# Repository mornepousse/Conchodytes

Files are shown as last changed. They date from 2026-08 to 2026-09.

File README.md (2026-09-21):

<h1 align="center">Conchodytes</h1>

<p align="center">
  <em>The shrimp that lives inside another's shell.</em><br>
  <em>La crevette qui vit dans la coquille d'un autre.</em>
</p>

---

## Firmware

The mouse runs the [KeSp firmware](https://github.com/mornepousse/KeSp_firmware)
(role `MOUSE`: PMW3389, three clicks, wheel, HID relayed to the dongle's slot 2).
Since 2026-09-21 **its board lives here**, not in the firmware repository:

- `boards/conchodytes/` — `board.h` (pinout, netlist-checked), `sdkconfig.defaults`,
  `test_pins.c` (the pinout contract);
- `firmware/` — the KeSp firmware as a git submodule, pinned on a release
  (`git submodule update --init`);
- `.github/workflows/firmware.yml` — calls the firmware's reusable workflow:
  every push builds `conchodytes_<version>.bin` (+ `_full.bin`), a `v*` tag
  publishes a release here.

```bash
scripts/test-pins.sh                                    # pinout contract, host, no toolchain
cd firmware && export IDF_COMPONENT_CHECK_NEW_VERSION=0 && \
idf.py -B build_conchodytes -DBOARD_DIR=../boards/conchodytes -DSDKCONFIG=build_conchodytes/sdkconfig build
esptool --chip esp32s3 -p /dev/ttyACM0 write_flash 0x20000 build_conchodytes/KeSp.bin
```

To take a newer firmware: `cd firmware && git fetch --tags && git checkout vX.Y.Z`,
then commit the submodule bump; read the firmware's release notes first (a
board macro may have been added — the pin contract will say).

## Firmware

The mouse runs the [KeSp firmware](https://github.com/mornepousse/KeSp_firmware)
(role `MOUSE`). Its board definition, pinout contract and firmware releases live
in **[Conchodytes-firmware](https://github.com/mornepousse/Conchodytes-firmware)**;
this repository is the hardware (PCB, notes, bring-up).

## English

A **sleeper mouse**: a replacement PCB for a Logitech M100 shell, keeping the
outer appearance of a cheap office mouse while carrying a **PMW3389** sensor and
a **wireless link to the [KeSp dongle](https://github.com/mornepousse/KeSp_dongle)** — the same receiver as the
[Niphargus](https://github.com/mornepousse/Niphargus) keyboard.

The shell is a fixed constraint: click switches, optical wheel encoder and sensor
positions are imposed by the M100 case and are locked in the layout.

Electronics reuse the reviewed and routed blocks of Niphargus — ESP32-S3 +
nRF24L01+, TP4056 charging with DW01A/FS8205 protection, HT7833 LDO, USB-C with
ESD protection.

## Français

Une **souris sleeper** : un PCB de remplacement pour coque Logitech M100, qui
garde l'apparence d'une souris de bureau bon marché tout en embarquant un capteur
**PMW3389** et une **liaison sans fil vers le [dongle KeSp](https://github.com/mornepousse/KeSp_dongle)** — le même récepteur
que le clavier [Niphargus](https://github.com/mornepousse/Niphargus).

La coque est une contrainte figée : les positions des clics, de l'encodeur
optique de molette et du capteur sont imposées par le boîtier M100, et
verrouillées dans le layout.

L'électronique reprend les blocs relus et routés du Niphargus — ESP32-S3 +
nRF24L01+, charge TP4056 avec protection DW01A/FS8205, LDO HT7833, USB-C protégé.

**État (2026-08-25)** — capteur **validé au banc** : identifié, SROM téléversé,
déplacement lu, sur trois reworks (voir `NOTES-V2.md`). Le firmware de banc est
dans `bringup/`.

**État (2026-08-07)** — schéma complet et vérifié par netlist, board **routé,
0 pad non connecté**. Le contour et les positions imposées par la coque viennent
du fork `USB-Mouse` ; l'alimentation, la charge, l'USB et la radio sont repris
du Niphargus. Reste à nettoyer le DRC (18 `copper_edge_clearance`) et à mesurer
la coque pour figer le contour définitif.

---

## Repository layout · Organisation

| Path | Contents |
|---|---|
| `hardware/pcb/` | KiCad project — `conchodytes.kicad_pro` |
| `scripts/` | Anti-regression checks (same pipeline as Niphargus) |
| `docs/` | Design notes |

### Fabrication

The two projects stay **independent**. They are only merged **at gerber export
time**, so the mouse board is panelised into the free space of the Niphargus
panel and costs almost nothing to make.

Les deux projets restent **indépendants**. Ils ne sont réunis qu'**au moment de
l'export gerber**, la carte souris venant se loger dans le vide du panneau
Niphargus — le PCB revient alors à presque rien.

### Anti-regression · Anti-régression

```sh
./scripts/check.sh --fast   # ERC vs committed baseline
./scripts/check.sh          # + full DRC
```

### Bloc capteur

| | |
|---|---|
| **PMW3389** | SPI partagé avec le nRF24 (`SCK_L`/`MOSI_L`/`MISO_L`), plus `SNS_NCS` et `SNS_MOTION`. Mode SPI **3**, `fSCLK` ≤ 2 MHz |
| **Alimentation** | ⚠️ VDD et VDDPIX **ne sont pas en 3,3 V** — rail dédié **2,0 V** par LDO (1,80-2,10 V, maximum **absolu** 2,10). VDDIO reste en 3,3 V |
| **Optique** | lentille **LM19-LSI**, commune au PMW3360 et au PMW3389 — celle d'origine de la M100 est faite pour le PAW3526 et ne convient pas |
| **Molette** | encodeur **optique** : LD1 éclaire une roue à 60 fentes, LQ1 la lit. ⚠️ `LQ1` (marquage `H6Y07`) est un capteur **VCC / GND / DATA**, PAS un double phototransistor — la v1 le câblait à l'envers, voir `NOTES-V2.md` §1bis |
| **Clics** | SPDT, COM à la masse, **NO et NC** tirés chacun au 3,3 V — lire les deux contacts en parallèle supprime le rebond |

Affectation des GPIO du S3, en évitant les broches de strapping :

| Signal | GPIO | Broche du module | | Signal | GPIO | Broche |
|---|---|---|---|---|---|---|
| `SNS_NCS` | 17 | 10 | | `SW_LEFT` | 10 | 18 |
| `SNS_MOTION` | 18 | 11 | | `SW_RIGHT` | 11 | 19 |
| `ENC_A` (DATA) | 7 | 7 | | `SW_MID` | 12 | 20 |
| `ENC_LED` ¹ | 9 | 17 | | `SW_LEFT_NC` | 5 | 5 |
| | | | | `SW_RIGHT_NC` | 4 | 4 |
| | | | | `SW_MID_NC` | 6 | 6 |

¹ `GPIO9` portait `ENC_B` en v1, sur un montage faux. En v2 il **commande la
cathode de LD1** — la LED de molette peut donc être éteinte par le firmware,
ce qui compte sur une souris à batterie. `ENC_A` (GPIO7) est le seul signal de
l'encodeur, et c'est `ADC1_CH6`.

⚠️ Ne pas confondre **GPIO** et **numéro de broche du module** : ce tableau
donnait auparavant les broches en les présentant comme des GPIO.

⚠️ **`SW_LEFT_NC` et `SW_RIGHT_NC` étaient inversés ici** jusqu'au 2026-08-25.
Le tableau annonçait GPIO4 à gauche et GPIO5 à droite ; la netlist dit l'inverse
— GPIO4 va à `SW2.3` (clic droit, R109) et GPIO5 à `SW1.3` (clic gauche, R108).
Comme l'anti-rebond apparie NO et NC du **même** bouton, écrire le firmware sur
l'ancien tableau croisait les deux clics.

Le reste du brochage, relevé à la netlist au `kicad-cli` le 2026-08-25 :

| Signal | Broche | GPIO | | Signal | Broche | GPIO |
|---|---|---|---|---|---|---|
| `SCK_L` | 31 | 38 | | `CSN_1` (nRF) | 38 | 2 |
| `MISO_L` | 32 | 39 | | `CE_1` (nRF) | 39 | 1 |
| `MOSI_L` | 33 | 40 | | `IRQ_1` (nRF) | 34 | 41 |
| `VBAT_SENSE` ² | 21 | 13 (ADC2_CH2) | | `D-` / `D+` | 13 / 14 | 19 / 20 |
| J1 `TX` / `RX` | 37 / 36 | 43 / 44 | | J1 `IO0` | 27 | 0 |

² En **v2**, `VBAT_SENSE` passe sur la broche 12 = **GPIO8 = ADC1_CH7**. L'ADC2
de l'ESP32-S3 est partagé avec le driver Wi-Fi ; tant que la mesure y reste, le
Wi-Fi est interdit sur cette carte. Voir `NOTES-V2.md` point 7.

Les lignes SPI et de contrôle portent chacune 100 Ω en série (R16/R18/R30,
R36/R39/R41) — sans effet à 2 MHz.

Les contacts NC des trois clics sont câblés sur GPIO4/5/6, chacun avec son
pull-up 10 k (R108-R110). Au repos NC est fermé sur COM donc bas, NO ouvert donc
haut ; au clic ils s'inversent. **Pendant le rebond les deux sont hauts** — le
firmware garde alors l'état précédent, ce qui élimine le double-clic sans aucun
filtrage temporel.

Les six empreintes imposées par la coque — SW1/SW2/SW3, LD1, LQ1, U2 — sont
**verrouillées** dans le layout et liées à leurs symboles. Ne pas les renommer :
le F8 les dissocierait et leurs positions seraient perdues.

## Historique · History

| Étape | Ce qui s'est passé |
|---|---|
| **REV1** | Premier tirage. Trois défauts de conception trouvés au banc, tous documentés dans `NOTES-V2.md` : `LQ1` câblé à l'envers (§1bis), `U100` — le LDO du capteur — pattes 2 et 3 croisées, et `U2` monté à 180°. |
| **2026-08-25** | Bring-up du capteur. La puce n'est **pas** un PMW3360 mais un **PMW3389** (`Product_ID = 0x47`) : identité lue, SROM téléversé, déplacement mesuré. Rail capteur corrigé au fer, **2,01 V mesuré**. Rotation de 180° confirmée par la mesure — les deux axes inversés, biais 100 % sur 76 échantillons. |
| **REV2.0.0** | Schéma corrigé et gerbers partis en fabrication : `LQ1` recâblé sur `+3V3`, `D100` supprimée, `VBAT_SENSE` déplacé sur ADC1, `U100` corrigé, `LD1` passée en cathode pilotée. |
| **2026-08-26** | Firmware complet et lien radio. La souris parle au dongle KaSe sur le slot RF 2 — le code vit comme septième variante de carte dans `KeSp_firmware`, pas dans un dépôt séparé. |

### Ce que la mise au point du 26 août a trouvé

Quatre défauts, chacun établi par une mesure prise **aux deux extrémités du
lien** — compteurs de la souris d'un côté, `RF_STATUS` du dongle de l'autre.

| Défaut | Avant | Après |
|---|---|---|
| Bascule de mode SPI sous un CS déjà abaissé — bus partagé entre le capteur (mode 3) et la radio (mode 0) | 1 trame acquittée sur 738 | 693 sur 693 |
| Scrutation du dongle à 10 ms, pour une FIFO nRF24 de 3 paquets | 3135 acceptées sur 8356 (37,5 %) | 99-100 % |
| Déplacement des trames non acquittées **jeté** au lieu d'être réaccumulé | la moitié du geste disparaissait | distance conservée |
| Résolution jamais écrite : la puce restait à son défaut | 5000 cpi | 1000 cpi, comme la M100 |

### Ce qui reste ouvert

Un tremblement d'**origine optique** que le firmware ne peut pas corriger :
`SQUAL` mesuré entre 30 et 55 là où ~80 est attendu, et le capteur produit sur
certaines surfaces des dérives cohérentes de ~1000 comptes en trois secondes,
souris immobile — indiscernables d'un geste lent volontaire.

Deux pistes, par ordre de coût croissant, détaillées au **§8 de `NOTES-V2.md`** :

1. **`R102`** vaut 330 Ω sous 3,3 V, soit ~6,8 mA dans `LD1`, quand la M100
   d'origine en fait passer 2,6 mA. La LED de molette tourne à près du triple de
   son intensité prévue, en permanence, contre le capteur. **820 Ω** reproduit
   le point de fonctionnement d'origine. Un composant.
2. **Le montage à 180° de `U2`** échange peut-être les chemins d'illumination et
   d'imagerie de la lentille, ce qui expliquerait l'image à la fois sombre en
   moyenne et saturée par endroits. Si c'est le cas, la rotation d'empreinte
   prévue en REV2 corrige le tremblement **et** le sens des axes d'un coup.

## Credits

Outline and mechanical positions derive from
[RandomDelta6/USB-Mouse](https://github.com/RandomDelta6/USB-Mouse), a working
USB mouse PCB reusing the original optical assembly.

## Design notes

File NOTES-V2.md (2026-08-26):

# Conchodytes v2 — relevés de banc

Notes prises au montage et au test de la **v1**, à reporter dans le layout de la
v2. Chaque point vient d'une observation sur carte réelle, pas d'une relecture
de schéma.

**Banc au 2026-08-25** — chaîne d'alimentation validée : batterie → protection
DW01A/FS8205 → Q2 (power-path) / D52 → **U20 HT7833 : 3,3 V mesuré et bon en
sortie**.

**Capteur validé le 2026-08-25**, après deux reworks au fer — le rail (`U100`
pins 2 et 3 croisées, voir `NOTE-LDO-PMW3360.md`) et la LED (§6) : identité lue,
SROM téléversé, déplacement mesuré, rail **mesuré à 2,01 V**. Le firmware de banc qui a servi
est dans `bringup/` — carte sur `/dev/ttyUSB2` via le FT2232 sur J1.

---

## 0. La puce n'est pas un PMW3360 — c'est un PMW3389

Lu sur la carte le 2026-08-25 : `Product_ID = 0x47`, `Inverse_Product_ID = 0xB8`,
`Revision_ID = 0x01`. Ce sont les valeurs par défaut du **PMW3389DM-T3QU**
(datasheet PixArt, Version 1.0 | 07 sep 2017, Table du §5.1, p. 20), pas celles
du PMW3360 (0x42 / 0xBD, p. 18 de sa propre datasheet). C'est **voulu** ; c'est
le dépôt qui n'avait pas suivi.

*(Coquille de la datasheet 3389 au passage : elle annonce `Inverse_Product_ID`
= 0xB9, alors que `0x47 ^ 0xFF = 0xB8`, et c'est bien 0xB8 que la carte renvoie.
Attendre le complément exact — c'est en prime une vérification de bus gratuite.)*

### Ce que les deux puces ne partagent pas

| | PMW3360 | PMW3389 |
|---|---|---|
| `Product_ID` | 0x42 | **0x47** |
| Résolution | `Config1` (0x0F), 8 bits | **`Resolution_L`/`_H` (0x0E/0x0F), 16 bits** |
| 0x0D | `Control` | **`Ripple Control`** |
| Config5 | 0x2F | **0x2E/0x2F** |
| LiftCutoff timeout | 0x58 / 0x5A | **0x71 / 0x72** |
| PWM | — | **0x73 / 0x74** |
| `tSRAD` (lecture normale) | 35 µs | **160 µs** |
| `tSWW` / `tSWR` | 120 µs | **180 µs** |
| Résistance de LED (référence) | 39 Ω sur 1,9 V | **13 Ω sur 1,9 V** |
| **Blob SROM** | — | **différent, 99,6 % des octets** |

Ce qui **ne** change **pas** : `VDD` 1,80/1,90/**2,10** V, `VDDIO` 1,80-3,60 V,
`fSCLK` ≤ 2 MHz, la lentille **LM19-LSI**, le brochage 16 broches, et la broche
15 `LED_P` en anode de la LED interne.

⚠️ Sur le 3389 les **2,10 V sont un maximum absolu** (Table 3, p. 15), pas
seulement le haut de la plage d'emploi comme sur le 3360.

### À reprendre dans le dépôt

- le symbole KiCad `U2` porte encore la valeur `PMW3360` ;
- `PMW3360.lib`, `PMW3360.pretty`, `NOTE-LDO-PMW3360.md` gardent leurs noms —
  le brochage 16 broches étant identique, l'empreinte reste valide, seul le nom
  ment ;
- le BOM et la commande LCSC.

---

## 1. U2 (PMW3389) — rotation de 180°

Le capteur est du bon côté de la carte, mais **orienté à l'envers** : l'axe Y est
inversé par rapport à l'axe de la souris.

| | v1 | v2 |
|---|---|---|
| Face | F.Cu | F.Cu (inchangé) |
| Position | (96,53 / 116,38) | inchangée |
| Rotation | 0° | **180°** |

La position ne bouge pas — elle est imposée par la coque M100 et l'empreinte est
verrouillée dans le layout. Seule la rotation change.

⚠️ **Ne pas renommer U2** en faisant la modification : le README rappelle que les
six empreintes imposées par la coque (SW1/SW2/SW3, LD1, LQ1, U2) sont liées à
leurs symboles, et qu'un F8 les dissocierait — leurs positions seraient perdues.

### ✅ Sens de rotation confirmé par la mesure (2026-08-25)

Protocole : passes dans **une seule direction**, souris soulevée pour le retour,
de sorte que le signe ne s'annule pas. Lecture par `Motion_Burst`, sommes signées
sur les échantillons amples.

| Geste | Convention HID | Mesuré | Biais |
|---|---|---|---|
| vers la **droite** | X positif | **X négatif** | 100,0 % sur 76 échantillons |
| vers l'**avant** | Y négatif (curseur monte) | **Y positif** | 99,8 % sur 71 échantillons |

**Les DEUX axes sont inversés.** C'est la signature exacte d'une rotation de
180° : une rotation quelconque mélangerait les axes (les deux paires varieraient
ensemble), un miroir n'en inverserait qu'un. Ici chaque axe reste propre — le
biais hors axe est de 50 % et d'amplitude 12 fois moindre — et les deux sont
retournés.

La correction proposée ci-dessus est donc la bonne, et le repli aussi :

- **rotation de 180° dans le layout** → les deux axes se remettent d'aplomb sans
  une ligne de firmware ;
- **si la lentille ne peut pas suivre** → le firmware nie `dx` et `dy`, deux
  signes moins, et le placement ne bouge pas.

Il ne reste donc plus qu'à vérifier **mécaniquement** si la LM19-LSI accepte la
rotation. La question logicielle, elle, est réglée.

**Question ouverte — la lentille.** Le PMW3389 travaille avec la lentille
**LM19-LSI** — la même que le 3360 (Figure 7, p. 10, et la note d'application
citée p. 13). Elle a ses propres ergots d'alignement sur le capteur et sur la
coque. Tourner le capteur de 180° peut imposer de tourner la lentille d'autant,
ce que la coque n'autorise peut-être pas. À trancher **avant** de figer le
layout : si la lentille ne peut pas suivre, la correction d'axe doit se faire
côté firmware plutôt que dans le placement.

*(Les deux datasheets sont maintenant indexées dans lemia : PMW3360DM-T2QU
`doc_id 6838`, PMW3389DM-T3QU `doc_id 6839`.)*

**Indice de banc à recouper avec ce point.** Le 2026-08-25, capteur à plat sur
l'établi **sans coque**, `SQUAL` fluctuait fortement au repos — de 12 à 73 sans
que rien ne bouge. Sur une optique correctement posée il devrait être stable. La
Table 4 (p. 15) veut **2,2 à 2,6 mm** entre le plan de référence de la lentille
et la surface suivie ; nue sur un établi la carte n'y est pas. À revérifier une
fois dans la M100 : si ça fluctue encore, c'est la lentille ou sa hauteur, pas le
capteur.

## 1bis. ⚠️ LQ1 EST CÂBLÉ À L'ENVERS — défaut de conception (BLOQUANT v2)

**Établi le 2026-08-26**, en confrontant le schéma d'origine de la M100
(`USB-Mouse-main/Mouse.sch`) au câblage de la Conchodytes.

`LQ1` n'est **pas** un double phototransistor A/COM/B. C'est un capteur à trois
fils **VCC / GND / DATA**. Marquage relevé sur le composant : **`H6Y07`**
(aucune datasheet trouvée).

### Le schéma d'origine, sans ambiguïté

```
(900, 6350) → label "Pin_4"    = LQ1 broche 1
(900, 6450) → label "Pin_2J"   = LQ1 broche 2
(900, 6550) → power:GNDREF     = LQ1 broche 3
```

`Pin_2J` n'est pas une masse : c'est le nœud d'alimentation, alimenté depuis
`Pin_2` à travers R12, et **partagé avec l'anode de LD1**.

### La comparaison

| `LQ1` | M100 d'origine | Conchodytes v1 | |
|---|---|---|---|
| broche 1 | `Pin_4` — **sortie DATA** | `ENC_A` + tirage 10 k | ✅ |
| broche 2 | `Pin_2J` — **VCC** | **la masse** | ❌ |
| broche 3 | **GNDREF** | `ENC_B` + tirage 10 k | ❌ |

**Le composant est alimenté à l'envers** : son VCC à la masse, sa masse tirée
vers le 3,3 V par R104.

### Ce que ça explique — toutes les mesures, sans exception

Le courant passe par la diode de substrat interne, de la broche GND du composant
vers sa broche VCC :

```
3,3 V → R104 (10 k) → broche GND du composant → jonction → broche VCC → masse
```

→ **0,65 V et 265 µA**, mesurés. Et par le même mécanisme sur la broche DATA
d'un circuit non alimenté.

| Observation | Expliquée |
|---|---|
| `ENC_A`/`ENC_B` à 0 en permanence | ✅ clampées à 0,65 V, sous le seuil VIL |
| Insensibles à la lumière (alu, scotch, R102 levée) | ✅ le composant n'est pas alimenté, la lumière n'y change rien |
| Impilotables même à 40 mA | ✅ une jonction en direct ne lâche pas |
| Invisibles à l'ohmmètre hors tension | ✅ le mode résistance travaille sous le seuil de conduction |
| **Identique sur DEUX composants différents** | ✅ c'est le comportement normal de ce câblage |

### Origine de l'erreur

Le symbole `Optical_Mouse:LQ`, hérité du fork `USB-Mouse`, ne nomme ses broches
que « 1, 2, 3 » **sans aucune fonction** :

```
X 1 1 -150    0 100 R 50 50 1 1 I
X 2 2 -150 -100 100 R 50 50 1 1 I
X 3 3 -150 -200 100 R 50 50 1 1 I
```

Le portage a donc supposé un A/COM/B classique. Rien dans le projet ne
contredisait cette supposition, et le schéma source n'a pas été consulté.

**À corriger en v2 :** donner des noms de broches au symbole (`DATA`, `VCC`,
`GND`) pour que l'erreur soit impossible à refaire, puis recâbler.

### ✅ Correction v2 — transposer le montage d'origine

> **APPLIQUÉE AU SCHÉMA le 2026-08-26.** Vérifiée à la netlist, ERC vert.
> **Le PCB n'est pas à jour** : ouvrir KiCad, « Mettre à jour le PCB depuis le
> schéma » (F8), puis reprendre le routage de ce coin.

**Principe retenu : reprendre le schéma de la M100 tel quel**, en transposant du
5 V USB au 3,3 V. C'est le seul montage dont on sait qu'il fonctionne avec ces
composants — et la récupération des pièces d'origine est le projet lui-même,
pas un pis-aller : un équivalent documenté et mécaniquement identique n'existe
probablement pas.

#### Le bloc encodeur de la M100

```
Pin_2 (VCC) ── JP1 (0 Ω) ──┬── Pin_2J ──┬── LQ1 broche 2  (VCC)
                           │            └── LD1 ANODE
                           └── C16 (non monté)

Pin_3 (Rot_LED) ── R14 (1500 Ω) ── LD1 CATHODE
Pin_4 (Rot_Enc) ─────────────────── LQ1 broche 1  (DATA)
GNDREF ──────────────────────────── LQ1 broche 3  (GND)
```

Deux traits à retenir : `LQ1` est **alimenté** (VCC/GND/DATA), et la **cathode
de LD1 est pilotée par le contrôleur**, pas câblée à la masse.

#### Le tableau des modifications

| Élément | v1 (faux) | **v2** |
|---|---|---|
| `LQ1.1` — DATA | `ENC_A` = GPIO7 | **inchangé** ✅ GPIO7 = `ADC1_CH6` |
| `LQ1.2` — VCC | **la masse** ❌ | **`+3V3`** |
| `LQ1.3` — GND | `ENC_B` = GPIO9 ❌ | **la masse** |
| `R103` 10 k sur `ENC_A` | +3,3 V → `ENC_A` | **garder** (inoffensive si la sortie est push-pull, nécessaire si collecteur ouvert) |
| `R104` 10 k sur `ENC_B` | +3,3 V → `ENC_B` | **supprimer** |
| `LD1` anode | `R102` → +3,3 V | **`+3V3` en direct** |
| `LD1` cathode | la masse | **`R102` → GPIO9**, renommé `ENC_LED` |
| `R102` | 330 Ω (netlist : 270) | **820 Ω** — voir calcul ci-dessous |

#### Pourquoi GPIO9 pour la LED

`ENC_B` disparaît en tant que signal, et `GPIO9` **arrive déjà physiquement dans
cette zone de la carte** — sa piste va aujourd'hui à `LQ1.3`. La réutiliser pour
commander la cathode de `LD1` évite de tirer une piste neuve à travers le
layout. Le routage change à peine.

À 2,6 mA, un GPIO de l'ESP32-S3 absorbe ce courant sans difficulté.

#### La valeur de R102

La M100 est en **5 V USB**, la Conchodytes en **3,3 V** : les valeurs ne se
recopient pas.

```
origine :  (5,0 − 1,16) / 1500 Ω  ≈  2,6 mA
v2      :  (3,3 − 1,16) / 820 Ω   ≈  2,6 mA
```

`Vf` = 1,16 V mesuré sous tension sur LD1. **820 Ω** reproduit donc exactement le
point de fonctionnement d'origine — nettement plus sobre que les 6,8 mA actuels,
ce qui est cohérent avec la saturation franche de `LQ1` observée au banc.

#### Ce que la LED pilotée apporte

1. **Autonomie.** La LED de molette peut être éteinte quand la souris dort. À
   2,6 mA en permanence, elle pèse lourd sur une batterie.
2. **Diagnostic.** Éteindre la LED par logiciel aurait réglé en une minute ce
   qui a pris une journée : plus besoin de lever `R102` au fer pour supprimer la
   source lumineuse.

#### Reste à caractériser : comment le sens de rotation sort d'un seul fil

La M100 défile dans les deux sens et `LQ1` n'a qu'une sortie — donc **cette
sortie porte l'information de sens**. Le mécanisme n'est pas établi.

Indice : ce contrôleur lit déjà **trois boutons sur un pont de résistances**
(`R13` = 1 MΩ, `R9`/`R10`/`R11` = 30 kΩ), donc par niveaux analogiques. Rien
n'interdit que `Rot_Enc` le soit aussi, `LQ1` combinant en interne ses deux
éléments en un niveau à plusieurs paliers.

*(Le `PAW3515DB`, même fabricant et même classe, utilise lui **deux** broches
`Z1`/`Z2` en quadrature classique — Figure 3, p. 3. Le `PAW3526D8` de la M100
est en boîtier 8 broches et n'en a pas les moyens : il doit caser VCC, GND, D+,
D−, trois clics, deux LED, le capteur et la molette sur huit pattes.)*

**L'expérience qui répond**, une fois la v2 câblée — ou dès maintenant avec deux
fils volants sur la v1 : alimenter `LQ1` correctement et **échantillonner
`ENC_A` à l'ADC** (`GPIO7` = `ADC1_CH6`) en tournant la roue.

- signal à **deux états** → un seul canal numérique, le sens vient d'ailleurs ;
- signal à **trois ou quatre paliers** → la quadrature est encodée en analogique,
  et un seul GPIO suffit à tout lire.

Le câblage v2 ci-dessus est bon dans les deux cas : il ne préjuge de rien et
respecte l'original.

### Note historique

Deux `LQ1` ont été dessoudés au cours du diagnostic, sur des conclusions
successives — « court franc à la masse », puis « composant mort » — toutes deux
fausses. **Les deux composants étaient sains.** Trois hypothèses ont été émises
et démenties avant que la confrontation au schéma d'origine ne donne la réponse.

La leçon : sur un composant repris d'un fork, **vérifier le schéma source avant
de faire confiance au symbole**, surtout quand celui-ci ne nomme pas ses
broches. Aucune mesure électrique ne pouvait révéler l'erreur — elles étaient
toutes cohérentes avec un câblage faux.

### Au passage : R102 vaut 330 Ω, pas 270

La netlist annonce 270 Ω, la valeur réellement montée sur la v1 est **330 Ω** —
à corriger dans le schéma pour qu'il cesse de mentir, **puis à remplacer par les
820 Ω du montage v2** (voir plus haut).

`LD1` est mesurée saine : `Vf` = 1,04 V en mode diode, **1,16 V sous tension**,
soit (3,3 − 1,16) / 330 ≈ **6,5 mA** aujourd'hui. La LED fonctionne — le
téléphone ne la voyait pas à cause de son filtre infrarouge, pas parce qu'elle
était éteinte.

## 2. Trou de maintien à gauche de la molette — à repositionner et à élargir

Découpe circulaire du contour, **Ø 1,00 mm, centre (85,85 / 93,36)**, juste sous
LD1 (la LED de l'encodeur), côté clic gauche.

Deux défauts constatés au montage :
- il est **trop petit** ;
- il n'est **pas à la bonne place**.

**Bloqué en attente de mesures sur la coque M100.** Ne rien corriger au jugé : le
diamètre et la position définitifs sortiront du relevé mécanique. Les deux autres
découpes du même secteur — Ø 1,50 mm à (105,47 / 94,09) et Ø 4,00 mm à
(112,91 / 93,29) — ne sont pas concernées par ce point, mais autant les vérifier
pendant qu'on a la coque et le pied à coulisse en main.

## 3. Clics en hotswap

Passer SW1 / SW2 / SW3 sur des **supports hotswap** au lieu du soudé direct, pour
pouvoir changer les switches sans fer.

État v1 : empreinte `Mouse:SPDT_Switch` — trois pastilles **traversantes en
ligne, pas de 5,08 mm, perçage 1,2 mm** (le brochage classique des switches de
souris type Omron D2FC).

Points à trancher avant de router :
- **Référence du support** à choisir (les sockets hotswap pour switch de souris
  existent, mais le brochage exact et l'empreinte dépendent du modèle). Vérifier
  la disponibilité LCSC avant de dessiner l'empreinte.
- **Face de montage** : ces supports se soudent en général sur la face *opposée*
  au switch. SW1/SW2/SW3 étant en F.Cu, les supports iraient en B.Cu — il faut
  donc de la garde verticale sous la carte à cet endroit.
- **La coque est une contrainte figée.** La hauteur ajoutée par le support
  déplace le switch de l'épaisseur du socket ; si la course du clic est déjà
  juste dans la M100, ça peut suffire à casser le ressenti, voire à empêcher la
  coque de fermer. À mesurer avant de s'engager.
- Le montage NO + NC anti-rebond (COM à la masse, les deux contacts tirés au
  3,3 V, GPIO 4/5/6 et 10/11/12) doit être conservé : le support doit donc bien
  reprendre **les trois broches**, pas seulement COM et NO.

## 4. Découpe interne de la molette — revoir le côté gauche

La fente de passage de la molette est un contour interne allant de
**x 87,32 à 106,35** et **y ≈ 84 à 99,98**. Son bord gauche n'est pas droit : il
porte un **décrochement**.

```
        x=87,32   x=90,27
           |         |
  y=86,46  |     +---+           <- le bord gauche commence a x=90,27
           |     |
  y=92,45  +-----+               <- puis saute a x=87,32 : le decrochement
           |
           |     ( molette )
           |
  y=99,98  +---------------------+  x=106,35   <- bord bas
```

Segments concernés, à revoir ensemble :
`(87,315 · 86,458)→(90,269 · 86,458)`, `(90,269 · 86,458)→(90,269 · 92,456)`,
`(90,269 · 92,456)→(87,315 · 92,448)`, `(87,315 · 92,448)→(87,315 · 99,978)`.

Au-dessus de y = 92,45 la fente est **2,95 mm plus étroite** qu'en dessous. À
confirmer sur la coque : soit le décrochement est justifié par un ergot de la
M100 et il faut le garder tel quel, soit c'est un reliquat du fork `USB-Mouse` et
la fente doit être droite sur toute sa hauteur.

**Même zone que le point 2** (le trou de maintien Ø 1,00 mm à gauche) et que
R102 au point 5 : tout le coin gauche de la molette est à reprendre d'un bloc,
à partir du même relevé mécanique. Ne pas traiter ces trois points séparément.

## 5. Éloigner D52 et R102 de la molette

Les deux composants sont en **F.Cu, soit la face de la molette**, et posés juste
sous le bord bas de sa découpe (y = 99,978) :

| Réf | Rôle | Empreinte | Centre | Garde au bord de la fente |
|---|---|---|---|---|
| **R102** | résistance série de LD1 (LED de l'encodeur) — **330 Ω montée**, 270 Ω au schéma, **820 Ω en v2** (§1bis) | 0603 | (87,90 · 103,10) | **1,90 mm** |
| **D52** | SS14, diode d'alimentation (USB +5 V → VIN de U20) | **D_SMA** | (104,90 · 103,10) | **2,22 mm** |

Les éloigner par sécurité. Deux raisons distinctes :

- **D52** est en boîtier **SMA** — nettement plus haut qu'un 0603 — et se trouve
  sous la partie droite de l'ouverture. C'est le plus exposé au frottement de la
  roue ou de son axe.
- **R102** est à 1,90 mm seulement, et se trouve **dans l'emprise en x de la
  fente** (87,43-88,38, quand la fente commence à 87,32) : elle est franchement
  sous l'ouverture, dans le coin gauche déjà signalé aux points 2 et 4.

La garde visée dépend de l'encombrement réel de la roue et de son support —
**à sortir du même relevé mécanique** que les points 2 et 4, pas à choisir au
jugé. R102 doit rester courte vers LD1 (83,97 · 89,46), mais un 0603 de LED n'a
aucune contrainte de routage : elle peut descendre ou partir vers la gauche
sans conséquence électrique.

## 6. D100 est de trop, et R101 a la mauvaise valeur

**Résolu au banc le 2026-08-25** — c'était bien la seule cause de l'aveuglement
du capteur. Chiffres avant / après en fin de section.

Datasheet **PMW3389DM-T3QU** (PixArt, Version 1.0, 07 sep 2017) :

- **p. 4** : « *a power control circuit and **built-in LED driver integrated with
  IR LED** in a package* ».
- **p. 5**, Table 1 (brochage) : broche **15**, `LED_P`, type **Input**,
  description « **LED Anode** ».

Le capteur embarque sa LED infrarouge. La broche 15 est l'anode de cette LED
interne, à alimenter depuis un rail via une résistance de limitation. **Il n'y a
aucune LED externe à monter** — D100 (« IR 940nm », 0805) n'a pas lieu d'être.

Pire, telle que la carte est routée :

```
  +3.3V ── D100 pad1 (CATHODE) ── pad2 (ANODE) ── R101 100R ── LED_P
```

La LED est traversée à l'envers : elle **bloque** le courant. La LED interne du
capteur ne s'allume pas et le capteur est aveugle.

### Montage de référence

**Figure 10, p. 14** de la datasheet **3389** (*Reference Schematic diagram for
PMW3389DM-T3QU*), lue en la rendant en image :

```
  VDD_1.9V ── R2 = 13 R ── broche 15 (LED1_P)
```

L'alimentation de la LED vient du **rail capteur 1,9 V**, pas du 3,3 V, à travers
**13 Ω** — et non les 39 Ω du 3360. Le 3389 tire nettement plus de courant.

La même figure donne aussi `R1 = 10 kΩ` depuis le 3,3 V en tirage de `NRESET`,
ce que la carte fait déjà avec R100.

En reprenant la chute LED + driver interne de ≈ **1,43 V** déduite du schéma de
référence du 3360, on retrouve (1,9 − 1,43) / 13 ≈ **36 mA** — cohérent avec
l'`IDDRUN` de 21 mA moyen *LED comprise* du 3389 (p. 1 et p. 18), la LED étant
découpée en rapport cyclique. ⚠️ Cette chute de 1,43 V est **déduite**, jamais
lue dans une table du 3389 : toute valeur de résistance qui en sort doit être
vérifiée au voltmètre.

### Correction appliquée sur la v1 le 2026-08-25

Aucune piste coupée.

1. **D100 pontée.** C'est elle qui bloquait : routée cathode vers le +3,3 V, elle
   empêchait tout courant d'atteindre `LED_P`. Tant qu'elle est là, la valeur de
   R101 n'a aucune importance.
2. **R101 remplacée par 22 + 39 Ω en série = 61 Ω**, alimentée depuis le 3,3 V :
   (3,3 − 1,43) / 61 ≈ **30,7 mA**, soit 15 % sous les 36 mA de la référence.
   Volontairement du côté sobre — la LED est un gros poste sur une souris à
   batterie, et la mesure a montré qu'il reste énormément de marge optique.
3. Alimenter `LED_P` en 3,3 V est licite : **Table 3, p. 15** donne
   `VIN −0,5 … 3,6 V — All I/O pins`, et `LED_P` est typé *Input*.

⚠️ L'ancienne recommandation de cette note — **150 Ω depuis le 3,3 V** — visait
les 12 mA du **3360**. Sur le 3389 elle sous-alimente la LED d'un facteur 3.
Ne pas la réutiliser.

### Résultat mesuré

| | avant | après |
|---|---|---|
| `Shutter` | **4500** (plafond, obturateur grand ouvert) | **~50** |
| `SQUAL` | 3-5 | **48-81** |
| `dx` / `dy` | 0 en permanence | jusqu'à ±5000 par fenêtre de 200 ms |
| `MOTION` (GPIO18) | jamais actif | bascule à 0 sur mouvement |

Un obturateur qui passe de 4500 à 50, c'est un facteur 88 de lumière en plus.
Diagnostic confirmé : c'était D100, et rien d'autre.

### Correction pour la v2

> **APPLIQUÉE AU SCHÉMA le 2026-08-26.** `D100` supprimée, `R101` = 16 Ω
> alimentée depuis `+2V0`, rail renommé `+1V8` → `+2V0`. Netlist vérifiée :
> `+2V0` contient `R101.2`, et `Net-(U2-LED_P)` relie `R101.1` à `U2.15`.
> **PCB à mettre à jour.**

1. **Supprimer D100** du schéma, et avec lui la ligne 18 de
   `Niphargus/hardware/order-lcsc-actifs.csv` (« A CHOISIR … LED infrarouge
   940nm ») : il n'y a pas de référence à choisir, il n'y a pas de composant.
2. **R101 = 16 Ω, alimentée depuis le rail capteur** (`+2V0` après la correction
   du point U100), et non depuis le 3,3 V — comme Figure 10, p. 14.
   Le rail visé étant 2,0 V et non les 1,9 V du schéma de référence :
   (2,0 − 1,43) / 16 ≈ **35,6 mA**, soit le courant de la référence. Les 13 Ω de
   PixArt donneraient 43,8 mA sur 2,0 V, un peu haut.
   *(Le banc ayant montré une marge optique énorme à 30 mA, une valeur plus
   sobre — 22 Ω, soit 26 mA — est un arbitrage d'autonomie parfaitement
   défendable.)*
3. Penser à ce que le LDO U100 (XC6206P202, 120 mA) alimente **aussi** ce
   courant de LED, en plus du capteur — `IDDRUN` du 3389 est de 21 mA moyen LED
   comprise (p. 1), donc ça reste très large.

## 7. VBAT_SENSE : passer la mesure batterie sur ADC1

Le pont diviseur lui-même **ne change pas**. C'est la broche qui le reçoit qui
est mal choisie.

### Le pont est bon, on n'y touche pas

```
+BATT ──[ R64 1M ]──┬── VBAT_SENSE
                    │
                   [ R67 1M ]   [ C21 100nF ]
                    │            │
                   GND          GND
```

Rapport ÷2 : 4,2 V batterie pleine → 2,1 V à l'entrée, dans la plage de l'ADC.
Les 1 MΩ ne sont pas une étourderie mais un choix de consommation — **2,1 µA**
de fuite permanente, contre 21 µA avec un 100 k/100 k. Pour un objet qui passe
sa vie endormi, c'est le bon arbitrage, et **C21 (100 nF) est déjà présent** :
le condensateur d'échantillonnage de l'ADC puise dedans et non à travers le
1 MΩ, ce qui est exactement ce qui rend un pont haute impédance utilisable.

Reste l'erreur due au courant de fuite de la broche ADC sur 500 kΩ d'impédance
de Thévenin. Elle se rattrape par une **calibration deux points en firmware**
(batterie pleine / batterie basse contre un voltmètre) — de toute façon
nécessaire sur un ADC ESP32, pont basse impédance ou pas.

### Ce qui change : la broche

Aujourd'hui `VBAT_SENSE` arrive sur la **broche 21** du module. Datasheet
**ESP32-S3-WROOM-1/1U, Table 3-1 *Pin Definitions*, p. 11** :

```
IO13    21    I/O/T    RTC_GPIO13, GPIO13, TOUCH13, ADC2_CH2, FSPIQ, FSPIIO7, SUBSPIQ
```

C'est donc **ADC2_CH2**. Or sur ESP32-S3 l'ADC2 est partagé avec le driver
Wi-Fi : tant que la mesure batterie est là, **le Wi-Fi est interdit sur cette
carte**. Ça marche aujourd'hui — la radio est un nRF24 et le firmware n'allume
jamais le Wi-Fi — mais c'est une hypothèque posée sur toutes les évolutions
futures, pour un gain nul.

**Décision : déplacer la mesure sur ADC1 en v2**, plutôt que d'inscrire
l'interdiction du Wi-Fi dans le marbre.

> **APPLIQUÉE AU SCHÉMA le 2026-08-26.** `VBAT_SENSE` est passée de `U6.21`
> (GPIO13, ADC2_CH2) à `U6.12` (**GPIO8, ADC1_CH7**). GPIO13 est libéré.
> **PCB à mettre à jour** : le pont R64/R67/C21 doit être rerouté de la
> rangée du bas vers la rangée de gauche du module, ~10 mm plus loin.

| | Broche module | GPIO | Canal | |
|---|---|---|---|---|
| Aujourd'hui | 21 | GPIO13 | ADC2_CH2 | à quitter |
| **Cible** | **12** | **GPIO8** | **ADC1_CH7** | libre, hors broches de strapping |

`GPIO8` est aujourd'hui non connecté sur la carte, et n'est pas une broche de
strapping. Ses autres fonctions (TOUCH8, SUBSPICS1) ne sont pas utilisées.

**Alternative écartée** : broche 15 = `GPIO3` = ADC1_CH2, libre elle aussi, mais
la même page 11 la liste comme **broche de strapping** — à éviter pour une
entrée analogique tirée en permanence par un pont diviseur.

Conséquence layout : le pont R64/R67/C21 doit être rerouté de la broche 21 vers
la broche 12. Ce n'est pas un déplacement voisin — dans l'empreinte du module,
la broche 21 est sur la **rangée du bas** (offset local 0,635 / 9,50) et la
broche 12 sur la **rangée de gauche** (−8,75 / 5,71), soit ~10 mm d'écart et un
changement de côté.

## 8. Hauteur optique : la lentille de la M100 n'est pas taillée pour le PMW3389

**Statut : à mesurer au banc. Rien à corriger en firmware — c'est de la mécanique.**

### Ce qui a été observé

Sur le montage final — coque M100 complète, lentille d'origine en place, tapis de
souris — le capteur donne un SQUAL de **30 à 55** et un Shutter autour de **140**.
Plus tôt dans le projet, le même capteur sur la même carte donnait **SQUAL ~80
avec Shutter ~50** : plus d'exposition pour moins de qualité.

Le symptôme utilisateur est une souris qui « bouge toute seule » au repos. Mesuré
au banc le 2026-08-26, capteur immobile sur le tapis : six relevés sur trente
exactement nuls, et entre eux des bouffées de +8 à +24 comptes en x, avec un biais
directionnel constant — dx et dy toujours positifs, dans un rapport stable. Du
bruit aléatoire s'annulerait autour de zéro ; un biais constant, non.

Deux vérifications ont été faites avant d'accuser l'optique, et toutes deux
disculpent le firmware :

- **le bit MOT est bien consulté** depuis le 2026-08-26. Le burst rapatriait déjà
  l'octet Motion (offset 0) sans le lire : les registres Delta ne portent pas un
  déplacement nul en l'absence de mouvement, ils portent n'importe quoi. Le
  garde-fou est en place, et la dérive persiste — le capteur DÉCLARE réellement
  du mouvement ;
- **la disposition du burst est bonne.** Elle avait été établie par mesure, pas
  par une datasheet, donc l'offset SQUAL a été recoupé contre une lecture directe
  du registre 0x07 : les deux concordent (45/45, 41/41, 46/46, 32/31). Le SQUAL
  bas est réel, ce n'est pas un mauvais octet.

### La spécification

Datasheet **PMW3389DM-T3QU v1.0 (07 sep 2017), p. 15, Table 4 « Recommended
Operating Condition »** :

> *Distance from Lens Reference Plane to Tracking Surface — **Z : min 2,2 / typ
> 2,4 / max 2,6 mm***

Soit **±0,2 mm** autour de 2,4 mm. C'est serré.

### Pourquoi c'est suspect ici

La lentille montée est celle de la M100 d'origine, dessinée pour le **PAW3526D8**.
Qu'elle s'emboîte mécaniquement ne dit rien sur le Z qu'elle impose au PMW3389 :
deux capteurs de la même maison n'ont pas la même géométrie optique. Le choix de
la coque M100 est assumé et bon (des millions d'exemplaires, encore achetables) —
mais il ne s'étend pas automatiquement à son optique.

### À faire

1. **Mesurer le Z réel** : distance du plan de référence de la lentille à la
   surface, patins posés. La comparer aux 2,2–2,6 mm.
2. Si le Z est hors plage, deux voies : caler la lentille, ou passer à la lentille
   **LM19-LSI** que la datasheet référence (figure 7, p. 3 ; vue éclatée figure 6,
   p. 9) — au prix d'une découpe de coque, à arbitrer contre l'intérêt de garder
   une pièce M100 d'origine.
3. Ne rien conclure avant la mesure : voir le §1bis, où trois diagnostics affirmés
   sans mesure ont coûté deux composants dessoudés.

### Au passage : la résolution n'était pas réglée

Sans rapport avec l'optique, trouvé le même jour. Le firmware n'écrivait jamais
`Resolution_L`/`_H` (0x0E/0x0F) : la puce restait sur ce que le SROM lui laisse,
soit `L=0x64 H=0x00` — 100 pas de 50 cpi, donc **5000 cpi**. La valeur se recoupe
avec la datasheet, dont toutes les courbes de caractérisation (figures 11 et 12,
p. 19) sont tracées « at resolution of 5000cpi ». La souris allait donc **cinq
fois trop vite**.

Réglée à **1000 cpi**, la valeur de la M100 d'origine, par `BOARD_SNS_CPI` dans
`boards/conchodytes/board.h`. À noter : le tableau p. 20 donne `L=0x00 H=0x42`
comme défaut de **reset**, ce que le SROM ne laisse pas en place — d'où la
relecture systématique de la puce au démarrage plutôt qu'une confiance au tableau.

### Hypothèse : le §1 et le §8 sont le même défaut

**Établie le 2026-08-26 par recoupement. À vérifier mécaniquement — voir plus bas.**

Les relevés optiques sont contradictoires en apparence :

- le **Shutter** est passé de ~50 (relevés du 2026-08-25) à **~140** : le capteur
  réclame plus d'exposition, donc il reçoit **moins** de lumière ;
- et pourtant `Max_RawData` sature à **0x7F** pendant que `Min_RawData` reste à
  **0x00** : l'image contient des points brûlés.

Une image globalement sombre *et* saturée par endroits, ce n'est pas un défaut de
quantité de lumière — c'est un défaut de **direction** : un reflet vif au lieu
d'un éclairage rasant uniforme.

Or le **§1** établit, mesure à l'appui, que `U2` est monté **à 180°**. Une
lentille de souris n'est pas symétrique : elle porte un chemin d'**illumination**
(côté LED, éclairage rasant de la surface) et un chemin d'**imagerie** (côté
capteur). Tourner le capteur de 180° n'inverse pas seulement les axes — **ça
échange ces deux chemins**.

Cela expliquerait d'un seul coup le SQUAL à 30-55, la saturation locale, et le
fait que le tremblement **empire selon la surface** (une surface brillante rend
un reflet mal dirigé bien plus gênant qu'une surface mate).

#### Ce que ça change

1. La correction d'axes en firmware (`BOARD_SNS_ROT_180`, dépôt KeSp_firmware)
   répare le **signe** mais ne peut **structurellement pas** réparer l'optique.
   Confirmé en pratique : un filtre logiciel a été essayé le 2026-08-26 et
   rejeté — il mangeait les gestes fins sans calmer le tremblement.
2. La rotation d'empreinte prévue au §1 corrigerait **les deux défauts à la
   fois**. Le §1 cesse donc d'être un simple point de confort sur le sens des
   axes : il devient **bloquant pour la qualité de suivi**.
3. Si l'hypothèse tient, la question ouverte du §1 — « la lentille LM19-LSI
   accepte-t-elle la rotation dans la coque ? » — devient la question centrale
   du projet, pas un détail de layout.

#### La vérification, sans rien démonter

Regarder par où la lumière de la LED entre dans la lentille, et où se trouve
l'ouverture d'imagerie du capteur. Si les deux sont **échangés** par rapport au
montage d'origine de la M100, l'hypothèse est confirmée. Sinon elle tombe, et la
hauteur Z (ci-dessus) redevient la piste principale.

⚠️ Tant que cette vérification n'est pas faite, **ceci reste une hypothèse**. Le
§1bis rappelle ce que coûtent les conclusions matérielles affirmées sans mesure.

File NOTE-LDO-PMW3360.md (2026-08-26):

# ⚠️ U100 — le régulateur du capteur

> **RÉSOLU SUR LA v1 le 2026-08-25.** `U100` déposé et resoudé **pins 2 et 3
> croisées en l'air**, pin 1 (VSS) laissée sur sa pastille. Rail **mesuré à
> 2,01 V**, contre 2,72 V avant — le composant monté est donc bien un
> XC6206**P202**. Le capteur fonctionne. La correction du layout reste à faire
> pour la v2 (voir « Correction retenue » plus bas).
>
> ⚠️ Le titre du fichier dit `PMW3360` : **la puce montée est un PMW3389**
> (voir `NOTES-V2.md` §0). Les plages d'alimentation sont identiques, donc tout
> ce document reste valide — seul son nom ment.

Trouvé le 2026-08-09 en cherchant une référence LCSC pour ce régulateur. **Deux
défauts**, tous deux rattrapables tant que les gerbers n'ont pas été réuploadés.

## 1. Le rail n'est pas à la bonne tension

Le rail s'appelle `+1V8`. Or la datasheet PMW3389 (*Table 4, Recommended
Operating Condition*, page 15 — mêmes valeurs que le 3360, *Table 3*, page 14)
donne :

| Paramètre | Min | **Typ** | Max |
|---|---|---|---|
| VDD | **1,80** | **1,90** | 2,10 V |
| VDDIO | 1,80 | 1,90 | 3,60 V (doit être ≥ VDD) |

**1,80 V est le minimum absolu, pas la valeur nominale.** Un LDO 1,8 V avec sa
tolérance de ±2 % descend à 1,76 V, sous la spécification. Il faut viser 1,9 ou
2,0 V. VDDIO en 3,3 V reste correct.

⚠️ Et à l'autre bout, sur le 3389, **2,10 V est un maximum ABSOLU** (*Table 3,
Absolute Maximum Ratings*, page 15 : `VDD −0,5 … 2,10 V`), pas seulement le haut
de la plage d'emploi. Le rail à 2,72 V mesuré avant correction était donc
au-dessus du maximum absolu, pas simplement hors plage recommandée.

Consommation à couvrir sur le 3389 : `IDDRUN` = **21 mA** en moyenne, LED
comprise (page 1 et page 18). Un LDO de 100 mA minimum, 120 mA de préférence —
le XC6206P202 en donne 120.

## 2. Le brochage de l'empreinte ne correspond à aucun composant

`U100` porte `lib_id = Regulator_Linear:MCP1700x-330xxTT`, mais ce symbole a son
brochage **modifié pour le HT7833 SOT-89** (1=GND, 2=VI, 3=VO) — c'est le
symbole trafiqué hérité du Niphargus, où il avait déjà causé un bloquant. Il a
été copié ici avec une empreinte **SOT-23**, boîtier où ce brochage n'existe pas.

Le PCB câble donc : pad 1 → GND, **pad 2 → +3.3V**, **pad 3 → +1V8**.

Brochage réel du XC6206 (datasheet Torex, *PIN ASSIGNMENT*, page 2) :

| | SOT-23 | SOT-89 |
|---|---|---|
| VSS | 1 | 1 |
| VIN | **3** | **2** |
| VOUT | **2** | **3** |

⚠️ **En SOT-23, les broches 2 et 3 sont inversées par rapport au câblage.** Monté
tel quel, le 3,3 V arrive sur la **sortie** du régulateur. Le pass PMOS a sa diode
de substrat orientée drain (VOUT) → source (VIN) : elle conduit, et le rail
capteur se cale à 3,3 V moins une chute de diode.

**Vérifié au banc le 2026-08-25 : 2,72 V mesuré**, pour un maximum absolu de
2,10 V. Le capteur a survécu et fonctionnait — mais c'est de la dégradation
silencieuse, pas de la marge.

Il n'existe **aucun composant qui corrigerait ça par un simple changement de
référence.** Le brochage que la carte câble — `1=GND, 2=VIN, 3=VOUT` — est la
convention **SOT-89**, jamais une convention SOT-23. Le monde du SOT-23-3
n'utilise que `1=VSS, 2=VOUT, 3=VIN` (XC6206, ME6206) ou `1=VIN, 2=GND, 3=VOUT`
(MCP1700, AP2127) — et le second mettrait VIN sur la pastille de masse. `U100`
est un brochage SOT-89 posé sur une empreinte SOT-23 : la seule issue est de
croiser les deux pistes.

Ne pas se fier aux sites de résumé de datasheets : trois d'entre eux ont donné
trois brochages différents pour ce composant, aucun correct. Seul le tableau du
fabricant fait foi.

## Correction retenue

> **APPLIQUÉE AU SCHÉMA le 2026-08-26**, et pas de la façon prévue — en mieux.
> Plutôt que d'échanger les pistes du PCB, ce sont **les numéros de pad du
> symbole** qui ont été corrigés : `VI` porte désormais le pad **3** et `VO` le
> pad **2**, soit le brochage réel du XC6206 en SOT-23.
>
> Le schéma cesse ainsi de mentir — `VI` reste dessiné à gauche avec le 3,3 V,
> `VO` à droite avec le rail capteur — et la netlist devient juste d'elle-même :
> `U100.1 → GND`, `U100.2 → +2V0`, `U100.3 → +3.3V`.
>
> **PCB à mettre à jour** : c'est le F8 qui reportera l'échange sur les pistes.

**Garder le SOT-23 et échanger les pistes des pads 2 et 3 de `U100`**, puis
commander le **XC6206P202MR-G — LCSC `C2891260`** (2,0 V, SOT-23, 120 mA,
±2 % → 1,96-2,04 V, bien dans la plage 1,80-2,10).

C'est **gratuit en v2** : deux pistes à reprendre dans le layout, sur une carte
qu'il faut de toute façon rouvrir pour D100, R101 et la rotation de U2. Le
composant ne change pas.

*(Le **XC6206P192** — 1,9 V — serait encore plus juste : c'est exactement la
valeur typique de la Table 4 et celle du schéma de référence. Le P202 reste
parfaitement bon, il est simplement un cran au-dessus du centre de cible.)*

Sur la v1 déjà fabriquée, le croisement se fait **sans couper de piste** : ne
souder que la pin 1 sur sa pastille, relever les pins 2 et 3, et poser deux fils
fins croisés. Ne pas tenter de retourner le boîtier — en SOT-23 les pins 1 et 2
sont du même côté et la 3 en face, retourner échange 1 et 2, ce qui mettrait
**VOUT sur la masse**.

L'alternative — passer l'empreinte en **SOT-89**, où le brochage 1=VSS 2=VIN
3=VOUT correspond déjà au câblage — a été écartée : le voisin le plus proche
(`R102`) est à 3,86 mm du centre de `U100`, et un SOT-89 fait 4,6 × 4,3 mm pads
compris. Ça passerait tout juste, sur une carte dont la mécanique est figée par
la coque M100.

Penser à renommer le rail `+1V8` en `+2V0` pour que le schéma ne mente pas.

## Point tranché : VDDPIX (résolu le 2026-08-25)

La broche 3 du capteur est décrite comme « **VDDPIX — Power — LDO output** »
(*Table 1*, page 3 du 3360 ; nommée `VDCPIX`, « *LDO output for selective analog
circuit* », *Table 1*, page 5 du 3389) : c'est une **sortie** de régulateur
interne. Or le PCB la
relie au rail externe, en parallèle de VDD (pad 3 et pad 4 tous deux sur le même
net). La question était de savoir si PixArt le prescrit.

**Oui.** La figure a été lue en la rendant en image plutôt qu'en tentant d'en
extraire le texte. **Figure 10, page 12** (*Reference Schematics*, schéma
d'application filaire), bloc *Sensor Block* : les broches **3 (VDDPIX)** et
**4 (VDD)** sont toutes deux reliées au même rail `VDD6_SS`, tandis que la
broche **5 (VDDIO)** part sur `VDD4_3.3V`.

Le câblage du PCB est donc conforme au schéma d'application. **Rien à corriger
sur ce point.**

*(Au passage, la même figure a livré le montage de la LED — voir le point 6 de
`NOTES-V2.md`, où D100 se révèle être un composant de trop.)*

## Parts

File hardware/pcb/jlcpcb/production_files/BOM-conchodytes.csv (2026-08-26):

Comment | Designator | Footprint | LCSC | Quantity
AO3407 | Q2 | SOT-23 | C351408 | 1
DW01A | U23 | SOT-23-6 | C351410 | 1
ESP32-S3-WROOM-1 | U6 | ESP32-S3-WROOM-1U | C2913204 | 1
FS8205 | Q4 | SOT-23-6 | C32254 | 1
HT7833 | U20 | SOT-89-3 | C50936 | 1
SS14 | D52 | D_SMA | C2480 | 1
SW_SPDT | SW54 | SW_SPDT_PCM12 | C431540 | 1
TP4056-42-ESOP8 | U18 | SOIC-8-1EP_3.9x4.9mm_P1.27mm_EP2.41x3.3mm_ThermalVias | C16581 | 1
USBLC6-2SC6 | U54 | SOT-23-6 | C7519 | 1
USB_C_Receptacle_USB2.0_16P | J48 | USB_C_Receptacle_HRO_TYPE-C-31-M-12 | C165948 | 1
IR encodeur | LD1 | Rot_LED |  | 1
Left click | SW1 | SPDT_Switch |  | 1
Middle click | SW3 | SPDT_Switch |  | 1
Right Click | SW2 | SPDT_Switch |  | 1
photodetecteur | LQ1 | LQ1 |  | 1
5k1 | R92 | R_0603_1608Metric_Pad0.98x0.95mm_HandSolder |  | 1
1M | R67 | R_0805_2012Metric_Pad1.20x1.40mm_HandSolder |  | 1
820 | R102 | R_0603_1608Metric |  | 1
10k | R107 | R_0603_1608Metric |  | 1
10k | R110 | R_0603_1608Metric |  | 1
100 | R39 | R_0603_1608Metric_Pad0.98x0.95mm_HandSolder |  | 1
PMW3389 | U2 | PMW3360 |  | 1
100nF | C8 | C_0603_1608Metric_Pad1.08x0.95mm_HandSolder |  | 1
1M | R64 | R_0805_2012Metric_Pad1.20x1.40mm_HandSolder |  | 1
10k | R109 | R_0603_1608Metric |  | 1
100nF | C21 | C_0603_1608Metric_Pad1.08x0.95mm_HandSolder |  | 1
1uF | C103 | C_0603_1608Metric |  | 1
1k | R62 | R_0805_2012Metric_Pad1.20x1.40mm_HandSolder |  | 1
100nF | C1 | C_0603_1608Metric_Pad1.08x0.95mm_HandSolder |  | 1
NRF24L01_Breakout | U8 | NRF24L01 |  | 1
100nF | C100 | C_0603_1608Metric |  | 1
Battery | J10 | PinHeader_1x02_P2.54mm_Vertical |  | 1
10uF | C11 | C_1206_3216Metric_Pad1.33x1.80mm_HandSolder |  | 1
10uF | C29 | C_1206_3216Metric_Pad1.33x1.80mm_HandSolder |  | 1
100 | R70 | R_0603_1608Metric_Pad0.98x0.95mm_HandSolder |  | 1
1k | R73 | R_0805_2012Metric_Pad1.20x1.40mm_HandSolder |  | 1
100nF | C101 | C_0603_1608Metric |  | 1
Conn_02x03_Odd_Even | J1 | PinHeader_2x03_P1.27mm_Vertical |  | 1
100nF | C102 | C_0603_1608Metric |  | 1
100k | R60 | R_0603_1608Metric_Pad0.98x0.95mm_HandSolder |  | 1
100 | R16 | R_0603_1608Metric_Pad0.98x0.95mm_HandSolder |  | 1
10k | R105 | R_0603_1608Metric |  | 1
1uF | C27 | C_0805_2012Metric_Pad1.18x1.45mm_HandSolder |  | 1
100 | R18 | R_0603_1608Metric_Pad0.98x0.95mm_HandSolder |  | 1
16 | R101 | R_0603_1608Metric |  | 1
LDO 2V0 | U100 | SOT-23 |  | 1
10uF | C20 | C_1206_3216Metric_Pad1.33x1.80mm_HandSolder |  | 1
1uF | C3 | C_0805_2012Metric_Pad1.18x1.45mm_HandSolder |  | 1
10k | R34 | R_0603_1608Metric_Pad0.98x0.95mm_HandSolder |  | 1
5k1 | R90 | R_0603_1608Metric_Pad0.98x0.95mm_HandSolder |  | 1
10k | R108 | R_0603_1608Metric |  | 1
0 | R104 | R_0603_1608Metric |  | 1
100 | R30 | R_0603_1608Metric_Pad0.98x0.95mm_HandSolder |  | 1
100 | R41 | R_0603_1608Metric_Pad0.98x0.95mm_HandSolder |  | 1
10k | R2 | R_0603_1608Metric_Pad0.98x0.95mm_HandSolder |  | 1
10k | R100 | R_0603_1608Metric |  | 1
LED | D49 | LED_0805_2012Metric_Pad1.15x1.40mm_HandSolder |  | 1
10uF | C26 | C_1206_3216Metric_Pad1.33x1.80mm_HandSolder |  | 1
100 | R36 | R_0603_1608Metric_Pad0.98x0.95mm_HandSolder |  | 1
2k4 | R68 | R_0805_2012Metric_Pad1.20x1.40mm_HandSolder |  | 1
10uF | C24 | C_1206_3216Metric_Pad1.33x1.80mm_HandSolder |  | 1
10k | R106 | R_0603_1608Metric |  | 1
10k | R103 | R_0603_1608Metric |  | 1
nephargus_10mm_Cu | HS1 | Niphargus_10mm_Cu |  | 1

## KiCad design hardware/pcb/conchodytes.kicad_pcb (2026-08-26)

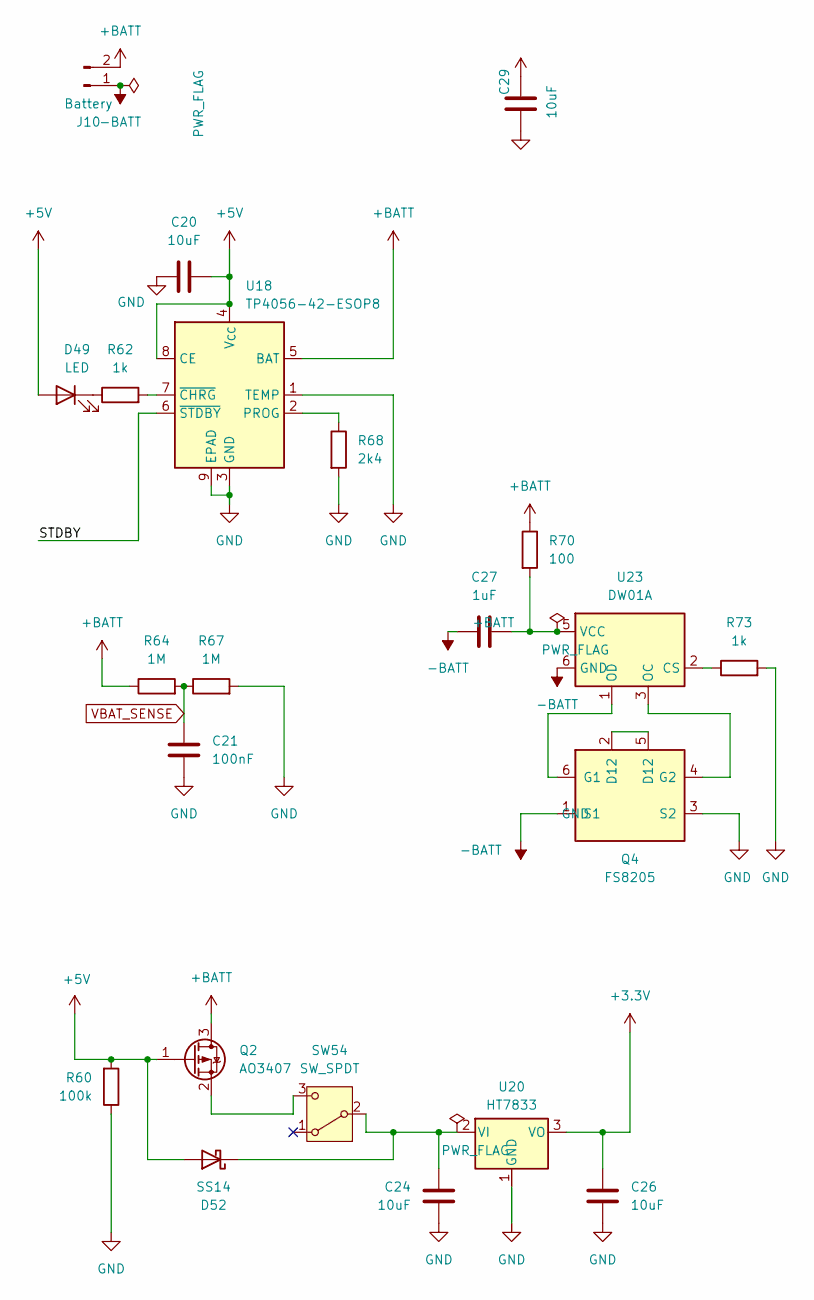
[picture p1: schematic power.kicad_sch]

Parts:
C20, C24, C26, C29: 10uF; C_1206_3216Metric_Pad1.33x1.80mm_HandSolder
C21: 100nF; C_0603_1608Metric_Pad1.08x0.95mm_HandSolder
C27: 1uF; C_0805_2012Metric_Pad1.18x1.45mm_HandSolder
D49: LED; LED_0805_2012Metric_Pad1.15x1.40mm_HandSolder
D52: SS14; D_SMA; LCSC C2480
J10: Battery; PinHeader_1x02_P2.54mm_Vertical
Q2: AO3407; SOT-23; LCSC C351408
Q4: FS8205; SOT-23-6; LCSC C32254
R60: 100k; R_0603_1608Metric_Pad0.98x0.95mm_HandSolder
R62, R73: 1k; R_0805_2012Metric_Pad1.20x1.40mm_HandSolder
R64, R67: 1M; R_0805_2012Metric_Pad1.20x1.40mm_HandSolder
R68: 2k4; R_0805_2012Metric_Pad1.20x1.40mm_HandSolder
R70: 100; R_0603_1608Metric_Pad0.98x0.95mm_HandSolder
SW54: SW_SPDT; SW_SPDT_PCM12; LCSC C431540
U18: TP4056-42-ESOP8; SOIC-8-1EP_3.9x4.9mm_P1.27mm_EP2.41x3.3mm_ThermalVias; LCSC C16581
U20: HT7833; SOT-89-3; LCSC C50936
U23: DW01A; SOT-23-6; LCSC C351410

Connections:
+3.3V: C26.2, U20.3 (VO); also elsewhere on the board
+5V: C20.2, D49.2 (A), D52.2 (A), Q2.1 (G), R60.2, U18.4 (V_{CC}), U18.8 (CE); also elsewhere on the board
+BATT: C29.1, J10.2, Q2.3 (D), R64.1, R70.1, U18.5 (BAT)
-BATT: C27.2, J10.1, Q4.1 (S1), U23.6 (GND)
/power/STDBY: U18.6 (~STDBY)
GND: C20.1, C21.1, C24.1, C26.1, C29.2, Q4.3 (S2), R60.1, R67.2, R68.2, R73.2, U18.1 (TEMP), U18.3 (GND), U18.9 (EPAD), U20.1 (GND); also elsewhere on the board
unnamed: D49.1 (K), R62.1
unnamed: C24.2, D52.1 (K), SW54.2 (B), U20.2 (VI)
unnamed: Q2.2 (S), SW54.3 (C)
unnamed: Q4.2 (D12), Q4.5 (D12)
unnamed: Q4.6 (G1), U23.1 (OD)
unnamed: Q4.4 (G2), U23.3 (OC)
unnamed: R68.1, U18.2 (PROG)
unnamed: R62.2, U18.7 (~CHRG)
unnamed: R73.1, U23.2 (CS)
unnamed: C27.1, R70.2, U23.5 (VCC)
VBAT_SENSE: C21.2, R64.2, R67.1; also elsewhere on the board

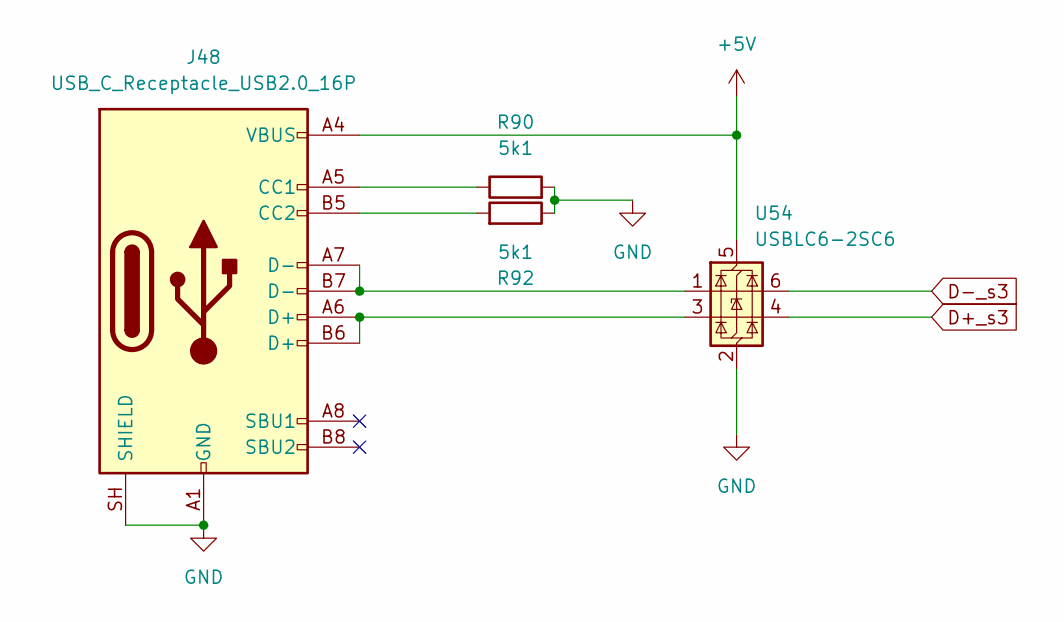
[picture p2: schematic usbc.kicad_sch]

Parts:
J48: USB_C_Receptacle_USB2.0_16P; USB_C_Receptacle_HRO_TYPE-C-31-M-12; LCSC C165948
R90, R92: 5k1; R_0603_1608Metric_Pad0.98x0.95mm_HandSolder
U54: USBLC6-2SC6; SOT-23-6; LCSC C7519

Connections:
+5V: J48.A4 (VBUS), J48.A9 (VBUS), J48.B4 (VBUS), J48.B9 (VBUS), U54.5 (VBUS); also elsewhere on the board
D+_s3: U54.4 (I/O2); also elsewhere on the board
D-_s3: U54.6 (I/O1); also elsewhere on the board
GND: J48.A1 (GND), J48.A12 (GND), J48.B1 (GND), J48.B12 (GND), J48.SH (SHIELD), R90.2, R92.1, U54.2 (GND); also elsewhere on the board
unnamed: J48.A5 (CC1), R90.1
unnamed: J48.B5 (CC2), R92.2
unnamed: J48.A6 (D+), J48.B6 (D+), U54.3 (I/O2)
unnamed: J48.A7 (D-), J48.B7 (D-), U54.1 (I/O1)

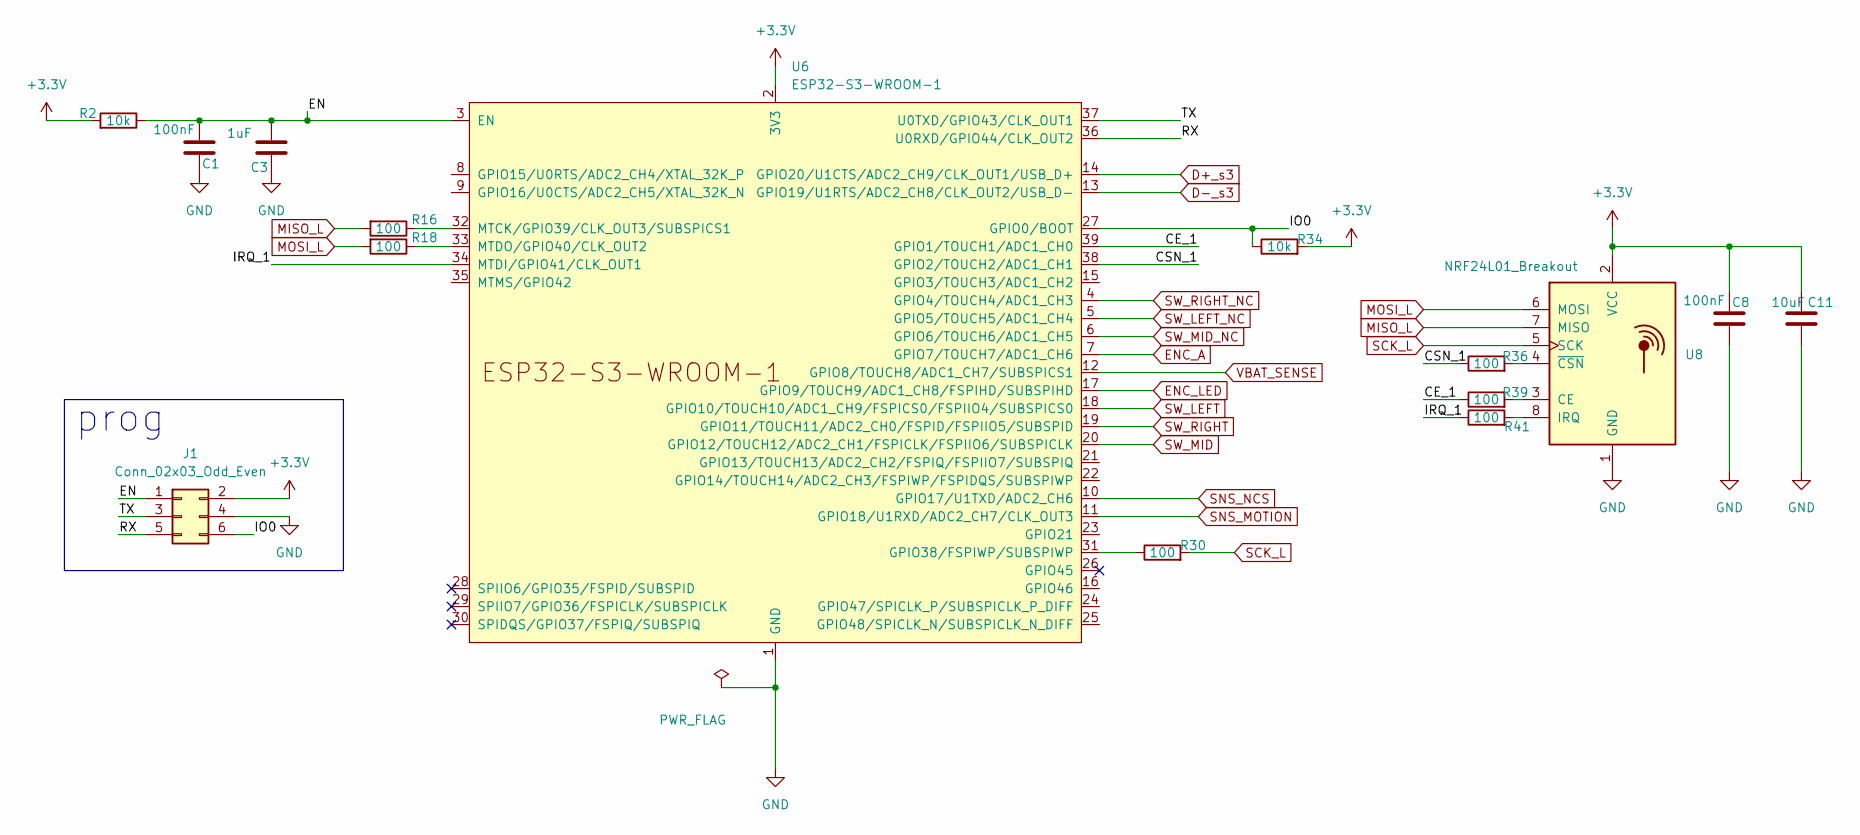
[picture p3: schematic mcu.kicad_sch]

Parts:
C1, C8: 100nF; C_0603_1608Metric_Pad1.08x0.95mm_HandSolder
C3: 1uF; C_0805_2012Metric_Pad1.18x1.45mm_HandSolder
C11: 10uF; C_1206_3216Metric_Pad1.33x1.80mm_HandSolder
J1: Conn_02x03_Odd_Even; PinHeader_2x03_P1.27mm_Vertical
R2, R34: 10k; R_0603_1608Metric_Pad0.98x0.95mm_HandSolder
R16, R18, R30, R36, R39, R41: 100; R_0603_1608Metric_Pad0.98x0.95mm_HandSolder
U6: ESP32-S3-WROOM-1; ESP32-S3-WROOM-1U; LCSC C2913204
U8: NRF24L01_Breakout; NRF24L01

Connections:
+3.3V: C8.2, C11.2, J1.2, R2.2, R34.2, U6.2 (3V3), U8.2 (VCC); also elsewhere on the board
/mcu/CE_1: R39.1, U6.39 (GPIO1/TOUCH1/ADC1_CH0)
/mcu/CSN_1: R36.1, U6.38 (GPIO2/TOUCH2/ADC1_CH1)
/mcu/EN: C1.2, C3.2, J1.1, R2.1, U6.3 (EN)
/mcu/IO0: J1.6, R34.1, U6.27 (GPIO0/BOOT)
/mcu/IRQ_1: R41.1, U6.34 (MTDI/GPIO41/CLK_OUT1)
/mcu/RX: J1.5, U6.36 (U0RXD/GPIO44/CLK_OUT2)
/mcu/TX: J1.3, U6.37 (U0TXD/GPIO43/CLK_OUT1)
D+_s3: U6.14 (GPIO20/U1CTS/ADC2_CH9/CLK_OUT1/USB_D+); also elsewhere on the board
D-_s3: U6.13 (GPIO19/U1RTS/ADC2_CH8/CLK_OUT2/USB_D-); also elsewhere on the board
ENC_A: U6.7 (GPIO7/TOUCH7/ADC1_CH6); also elsewhere on the board
ENC_LED: U6.17 (GPIO9/TOUCH9/ADC1_CH8/FSPIHD/SUBSPIHD); also elsewhere on the board
GND: C1.1, C3.1, C8.1, C11.1, J1.4, U6.1 (GND), U6.40 (GND), U6.41 (GND), U8.1 (GND); also elsewhere on the board
MISO_L: R16.2, U8.7 (MISO); also elsewhere on the board
MOSI_L: R18.2, U8.6 (MOSI); also elsewhere on the board
unnamed: R30.1, U6.31 (GPIO38/FSPIWP/SUBSPIWP)
unnamed: R16.1, U6.32 (MTCK/GPIO39/CLK_OUT3/SUBSPICS1)
unnamed: R18.1, U6.33 (MTDO/GPIO40/CLK_OUT2)
unnamed: R39.2, U8.3 (CE)
unnamed: R41.2, U8.8 (IRQ)
unnamed: R36.2, U8.4 (~CSN)
SCK_L: R30.2, U8.5 (SCK); also elsewhere on the board
SNS_MOTION: U6.11 (GPIO18/U1RXD/ADC2_CH7/CLK_OUT3); also elsewhere on the board
SNS_NCS: U6.10 (GPIO17/U1TXD/ADC2_CH6); also elsewhere on the board
SW_LEFT: U6.18 (GPIO10/TOUCH10/ADC1_CH9/FSPICS0/FSPIIO4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); also elsewhere on the board
SW_LEFT_NC: U6.5 (GPIO5/TOUCH5/ADC1_CH4); also elsewhere on the board
SW_MID: U6.20 (GPIO12/TOUCH12/ADC2_CH1/FSPICLK/FSPIIO6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); also elsewhere on the board
SW_MID_NC: U6.6 (GPIO6/TOUCH6/ADC1_CH5); also elsewhere on the board
SW_RIGHT: U6.19 (GPIO11/TOUCH11/ADC2_CH0/FSPID/FSPIIO5/S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); also elsewhere on the board
SW_RIGHT_NC: U6.4 (GPIO4/TOUCH4/ADC1_CH3); also elsewhere on the board
VBAT_SENSE: U6.12 (GPIO8/TOUCH8/ADC1_CH7/SUBSPICS1); also elsewhere on the board

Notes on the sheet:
prog

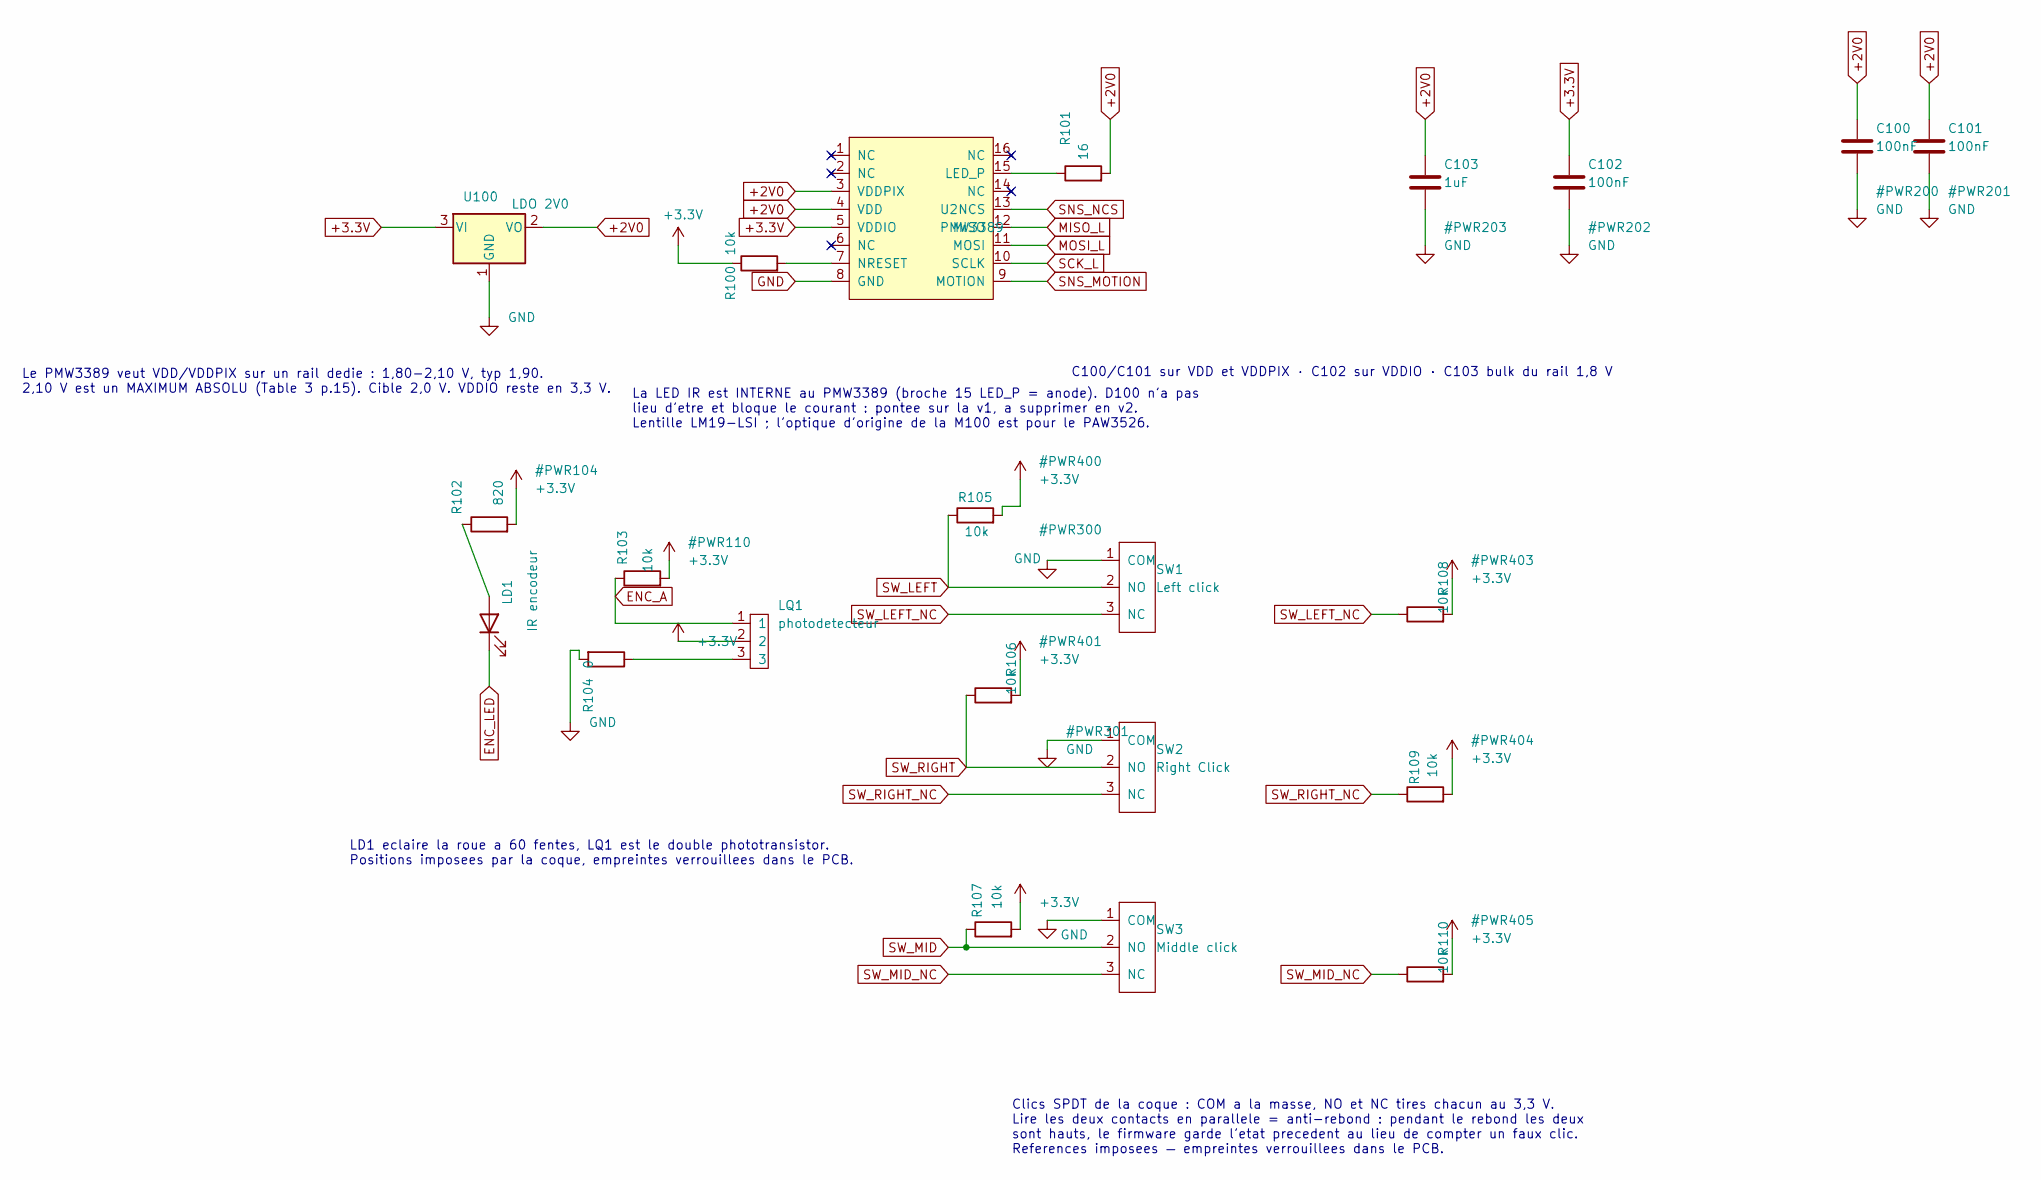
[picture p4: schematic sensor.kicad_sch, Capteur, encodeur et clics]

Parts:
C100, C101, C102: 100nF; C_0603_1608Metric
C103: 1uF; C_0603_1608Metric
LD1: IR encodeur; Rot_LED
LQ1: photodetecteur; LQ1
R100, R103, R105, R106, R107, R108, R109, R110: 10k; R_0603_1608Metric
R101: 16; R_0603_1608Metric
R102: 820; R_0603_1608Metric
R104: 0; R_0603_1608Metric
SW1: Left click; SPDT_Switch
SW2: Right Click; SPDT_Switch
SW3: Middle click; SPDT_Switch
U2: PMW3389; PMW3360
U100: LDO 2V0; SOT-23

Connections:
+2V0: C100.1, C101.1, C103.1, R101.2, U2.3 (VDDPIX), U2.4 (VDD), U100.2 (VO)
+3.3V: C102.1, LQ1.2, R100.1, R102.2, R103.2, R105.2, R106.2, R107.2, R108.2, R109.2, R110.2, U2.5 (VDDIO), U100.3 (VI); also elsewhere on the board
ENC_A: LQ1.1, R103.1; also elsewhere on the board
ENC_LED: LD1.1 (K); also elsewhere on the board
GND: C100.2, C101.2, C102.2, C103.2, R104.2, SW1.1 (COM), SW2.1 (COM), SW3.1 (COM), U2.8 (GND), U100.1 (GND); also elsewhere on the board
MISO_L: U2.12 (MISO); also elsewhere on the board
MOSI_L: U2.11 (MOSI); also elsewhere on the board
unnamed: LD1.2 (A), R102.1
unnamed: LQ1.3, R104.1
unnamed: R101.1, U2.15 (LED_P)
unnamed: R100.2, U2.7 (NRESET)
SCK_L: U2.10 (SCLK); also elsewhere on the board
SNS_MOTION: U2.9 (MOTION); also elsewhere on the board
SNS_NCS: U2.13 (NCS); also elsewhere on the board
SW_LEFT: R105.1, SW1.2 (NO); also elsewhere on the board
SW_LEFT_NC: R108.1, SW1.3 (NC); also elsewhere on the board
SW_MID: R107.1, SW3.2 (NO); also elsewhere on the board
SW_MID_NC: R110.1, SW3.3 (NC); also elsewhere on the board
SW_RIGHT: R106.1, SW2.2 (NO); also elsewhere on the board
SW_RIGHT_NC: R109.1, SW2.3 (NC); also elsewhere on the board

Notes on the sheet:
C100/C101 sur VDD et VDDPIX · C102 sur VDDIO · C103 bulk du rail 1,8 V
Clics SPDT de la coque : COM a la masse, NO et NC tires chacun au 3,3 V. Lire les deux contacts en parallele = anti-rebond : pendant le rebond les deux sont hauts, le firmware garde l'etat precedent au lieu de compter un faux clic. References imposees — empreintes verrouillees dans le PCB.
La LED IR est INTERNE au PMW3389 (broche 15 LED_P = anode). D100 n'a pas lieu d'etre et bloque le courant : pontee sur la v1, a supprimer en v2. Lentille LM19-LSI ; l'optique d'origine de la M100 est pour le PAW3526.
Le PMW3389 veut VDD/VDDPIX sur un rail dedie : 1,80-2,10 V, typ 1,90. 2,10 V est un MAXIMUM ABSOLU (Table 3 p.15). Cible 2,0 V. VDDIO reste en 3,3 V.
LD1 eclaire la roue a 60 fentes, LQ1 est le double phototransistor. Positions imposees par la coque, empreintes verrouillees dans le PCB.

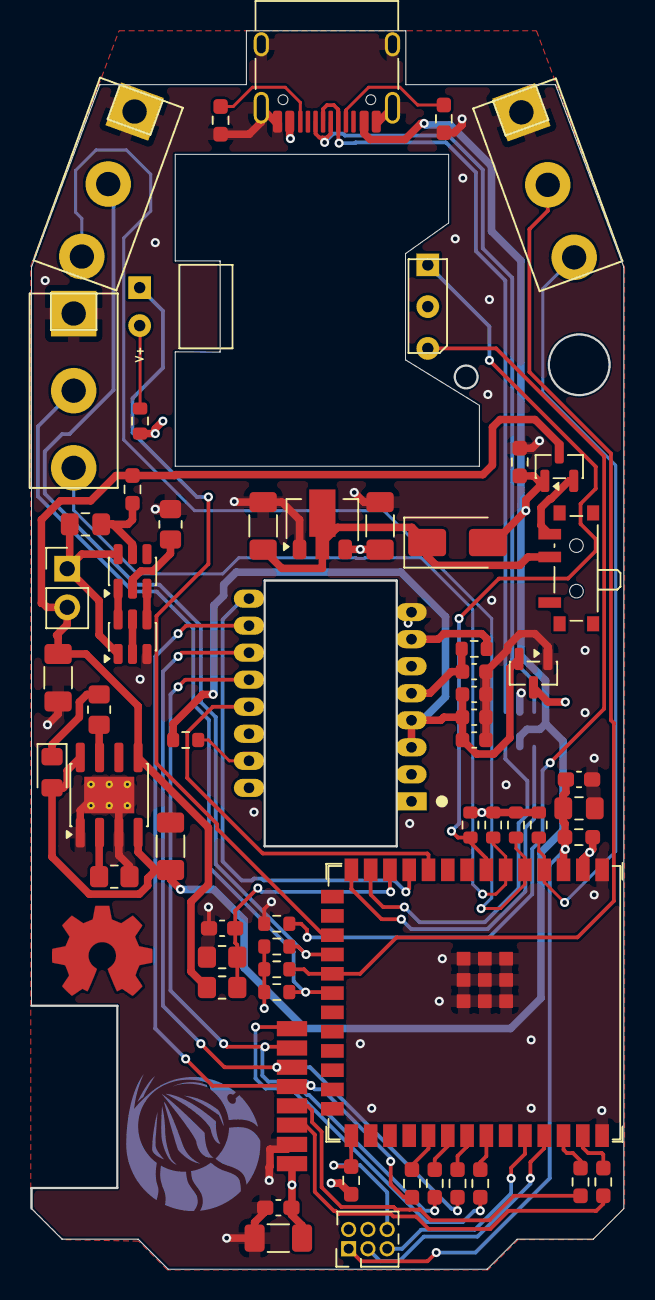
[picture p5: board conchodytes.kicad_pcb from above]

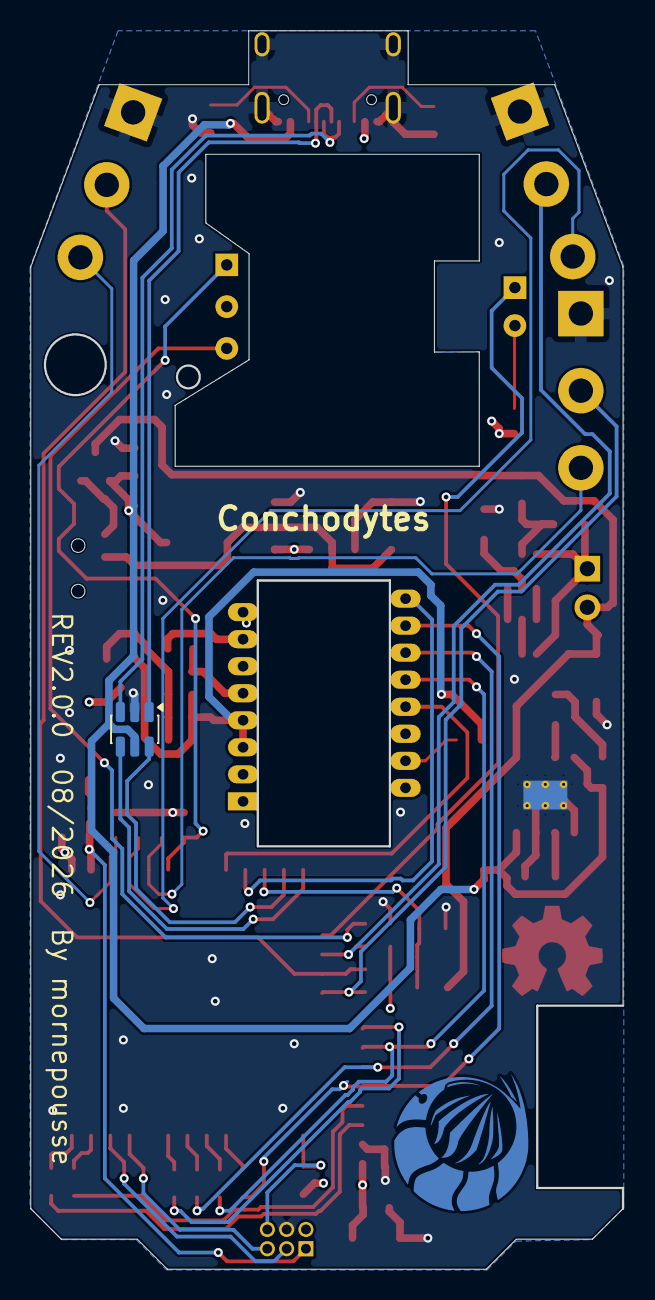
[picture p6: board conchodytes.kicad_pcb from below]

Board: 4 copper layers, 39.0 x 81.5 mm, 65 parts (2 on the bottom side), 53 nets.

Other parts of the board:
HS1: nephargus_10mm_Cu; Niphargus_10mm_Cu
HS2: OSHW-Symbol_6.7x6mm_Copper

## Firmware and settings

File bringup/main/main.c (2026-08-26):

/* Conchodytes — bring-up capteur PMW3389.
 *
 * Une seule question : est-ce que le capteur repond, et est-ce qu'il voit.
 *
 * LA PUCE MONTEE EST UN PMW3389DM-T3QU, PAS UN PMW3360. Product_ID lu sur la
 * carte le 2026-08-25 : 0x47, avec Revision_ID 0x01 — les deux valeurs par
 * defaut du 3389 (datasheet Version 1.0 | 07 sep 2017, p. 20). Tout le depot
 * (README, BOM, NOTES-V2.md, symbole KiCad U2) parle encore du 3360 : c'est le
 * depot qui a tort. Les deux puces ne partagent PAS leur blob SROM ni tout
 * leur plan de registres.
 * Pas de radio, pas de HID, pas de keymap. Sortie sur UART0 (J1).
 *
 * Brochage releve a la netlist de hardware/pcb/ au kicad-cli :
 *   SCK_L  = GPIO38   MISO_L = GPIO39   MOSI_L = GPIO40   (100 R en serie)
 *   SNS_NCS = GPIO17  SNS_MOTION = GPIO18
 *   nRF24 : CSN = GPIO2, CE = GPIO1  -> maintenus inactifs, bus partage.
 *
 * Datasheet PMW3389DM-T3QU, PixArt, Version 1.0 | 07 sep 2017 :
 *   Product_ID (0x00)         = 0x47   p. 20
 *   Revision_ID (0x01)        = 0x01   p. 20
 *   Inverse_Product_ID (0x3F) = 0xB9 annonce p. 20, mais 0x47 ^ 0xFF = 0xB8 et
 *     c'est 0xB8 que la carte renvoie. Coquille de la datasheet ; on attend le
 *     complement exact, qui est en plus une verification de bus gratuite.
 *   VDD 1,8-2,1 V / VDDIO 1,8-3,6 V     p. 1 et Table 4, p. 15
 *   Resolution sur 0x0E/0x0F (16 bits), et NON sur un Config1 8 bits comme le
 *     3360. Ce bring-up n'y touche pas : les valeurs de reset suffisent pour
 *     savoir si la puce detecte du mouvement, et ca supprime une inconnue.
 *
 * ATTENTION MATERIEL : sur la v1 sans rework, U100 est cable a l'envers
 * (pad 2 = VOUT sur +3V3, pad 3 = VIN sur le rail capteur). La diode de
 * substrat du PMOS pose le rail a ~2,7 V, au-dessus des 2,10 V de la plage
 * d'emploi (Table 4, p. 15). Deposer U100 et injecter 1,9 V sur C100/C101/C103 avant
 * d'accorder le moindre credit a ce que ce programme affiche.
 */

#include <stdio.h>
#include <string.h>
#include "freertos/FreeRTOS.h"
#include "freertos/task.h"
#include "driver/gpio.h"
#include "driver/spi_master.h"
#include "esp_rom_sys.h"
#include "esp_log.h"

static const char *TAG = "conch";

/* ── Brochage ───────────────────────────────────────────────────────────── */
#define PIN_SCK        GPIO_NUM_38
#define PIN_MISO       GPIO_NUM_39
#define PIN_MOSI       GPIO_NUM_40
#define PIN_SNS_NCS    GPIO_NUM_17
#define PIN_SNS_MOTION GPIO_NUM_18
#define PIN_NRF_CSN    GPIO_NUM_2
#define PIN_NRF_CE     GPIO_NUM_1
#define PIN_NRF_IRQ    GPIO_NUM_41

/* Clics : trois SPDT, COM a la masse, NO et NC tires chacun au 3,3 V par 10 k
 * (R105-R107 et R108-R110). ATTENTION : le README annoncait LEFT_NC sur GPIO4
 * et RIGHT_NC sur GPIO5 — c'est l'inverse. Valeurs ci-dessous relevees a la
 * netlist : GPIO4 va a SW2.3 (clic DROIT), GPIO5 a SW1.3 (clic GAUCHE). */
#define PIN_SW_LEFT       GPIO_NUM_10
#define PIN_SW_LEFT_NC    GPIO_NUM_5
#define PIN_SW_RIGHT      GPIO_NUM_11
#define PIN_SW_RIGHT_NC   GPIO_NUM_4
#define PIN_SW_MID        GPIO_NUM_12
#define PIN_SW_MID_NC     GPIO_NUM_6

/* Molette : encodeur optique, LD1 eclaire une roue a 60 fentes, LQ1 double
 * phototransistor -> deux voies en quadrature. */
#define PIN_ENC_A      GPIO_NUM_7
#define PIN_ENC_B      GPIO_NUM_9

#define SNS_SPI_HOST   SPI2_HOST
#define SNS_CLOCK_HZ   (2 * 1000 * 1000)   /* fSCLK max = 2,0 MHz, Table 4, p. 15 */

/* ── Registres, p. 20 ───────────────────────────────────────────────────── */
#define REG_Product_ID         0x00
#define REG_Revision_ID        0x01
#define REG_Motion             0x02
#define REG_Delta_X_L          0x03
#define REG_Delta_X_H          0x04
#define REG_Delta_Y_L          0x05
#define REG_Delta_Y_H          0x06
#define REG_SQUAL              0x07
#define REG_Shutter_Lower      0x0B
#define REG_Shutter_Upper      0x0C
#define REG_Resolution_L       0x0E   /* 3389 : 16 bits, pas le Config1 du 3360 */
#define REG_Resolution_H       0x0F
#define REG_Config2            0x10
#define REG_SROM_Enable        0x13
#define REG_SROM_ID            0x2A
#define REG_Power_Up_Reset     0x3A
#define REG_Inverse_Product_ID 0x3F
#define REG_Motion_Burst       0x50
#define REG_SROM_Load_Burst    0x62

extern const unsigned short firmware_length;
extern const unsigned char firmware_data[];

static spi_device_handle_t s_sns;

/* ── Transport SPI, CS pilote a la main ─────────────────────────────────────
 * Le CS materiel d'ESP-IDF le releverait entre l'octet d'adresse et l'octet de
 * donnee, or tSRAD tombe justement dans cet intervalle. D'ou spics_io_num = -1
 * et ces deux fonctions. Meme geste que main/comm/rf/rf_driver.c cote KeSp. */

static inline void cs_low(void)  { gpio_set_level(PIN_SNS_NCS, 0); esp_rom_delay_us(1); }
static inline void cs_high(void) { esp_rom_delay_us(1); gpio_set_level(PIN_SNS_NCS, 1); }

static void spi_tx(const uint8_t *tx, uint8_t *rx, size_t len)
{
    spi_transaction_t t = {
        .length    = len * 8,
        .tx_buffer = tx,
        .rx_buffer = rx,
    };
    ESP_ERROR_CHECK(spi_device_polling_transmit(s_sns, &t));
}

static uint8_t reg_read(uint8_t addr)
{
    uint8_t a = addr & 0x7F;      /* MSB a 0 = lecture */
    uint8_t d = 0;

    cs_low();
    spi_tx(&a, NULL, 1);
    esp_rom_delay_us(180);        /* tSRAD = 160 us MINIMUM sur le 3389 (Table 5,
                                   * p. 16) — contre 35 us sur le 3360. Le code de
                                   * reference d'ou vient ce driver attend 100 us :
                                   * hors spec ici, et c'est le genre d'ecart qui
                                   * passe au banc puis lache par intermittence. */
    spi_tx(NULL, &d, 1);
    cs_high();
    esp_rom_delay_us(20);         /* tSRW/tSRR = 20 us (Table 5, p. 16) */
    return d;
}

static void reg_write(uint8_t addr, uint8_t val)
{
    uint8_t buf[2] = { (uint8_t)(addr | 0x80), val };   /* MSB a 1 = ecriture */

    cs_low();
    spi_tx(buf, NULL, 2);
    esp_rom_delay_us(20);         /* tSCLK-NCS en ecriture */
    cs_high();
    esp_rom_delay_us(200);        /* tSWW/tSWR = 180 us mini sur le 3389 (p. 16) */
}

/* ── Televersement SROM ─────────────────────────────────────────────────────
 * 4094 octets a 15 us l'octet : ~61 ms pendant lesquelles rien d'autre ne doit
 * toucher le bus. acquire_bus le garantit face au nRF24. */
static void srom_upload(void)
{
    reg_write(REG_Config2, 0x20);        /* valeur par defaut du registre, p. 20 */
    reg_write(REG_SROM_Enable, 0x1D);
    vTaskDelay(pdMS_TO_TICKS(10));       /* plus d'une periode de trame */
    reg_write(REG_SROM_Enable, 0x18);

    uint8_t burst = REG_SROM_Load_Burst | 0x80;
    cs_low();
    spi_tx(&burst, NULL, 1);
    esp_rom_delay_us(15);
    for (unsigned i = 0; i < firmware_length; i++) {
        spi_tx(&firmware_data[i], NULL, 1);
        esp_rom_delay_us(15);
    }
    cs_high();
    esp_rom_delay_us(200);

    uint8_t srom_id = reg_read(REG_SROM_ID);
    ESP_LOGI(TAG, "SROM_ID = 0x%02X  (0x00 = televersement rate)", srom_id);

    /* 0x00 = mode filaire, Rest desactive : au banc on ne veut pas que la puce
     * s'endorme entre deux mesures. La resolution reste a sa valeur de reset. */
    reg_write(REG_Config2, 0x00);
}

/* Remise a zero du port serie du capteur, PUIS reset logiciel.
 *
 * A faire AVANT la toute premiere lecture de registre, et pas apres.
 * Constate sur carte le 2026-08-25 : en lisant Product_ID avant cette
 * sequence, la puce renvoyait 0x11 la ou elle vaut 0x47 — soit 0x47 >> 2,
 * un decalage de deux bits d'horloge. Les lectures suivantes etaient
 * alignees. La machine a etats SPI du capteur n'est pas dans un etat connu
 * a la mise sous tension ; le triple battement de NCS l'y remet. */
static void sensor_reset(void)
{
    cs_high(); cs_low(); cs_high();      /* remise a zero du port serie */
    reg_write(REG_Power_Up_Reset, 0x5A);
    vTaskDelay(pdMS_TO_TICKS(50));       /* tMOT-RST = 50 ms, Table 5, p. 16 */

    /* lire et jeter 0x02..0x06 apres le reset */
    (void)reg_read(REG_Motion);
    (void)reg_read(REG_Delta_X_L);
    (void)reg_read(REG_Delta_X_H);
    (void)reg_read(REG_Delta_Y_L);
    (void)reg_read(REG_Delta_Y_H);
}

static void sensor_load_srom(void)
{
    ESP_ERROR_CHECK(spi_device_acquire_bus(s_sns, portMAX_DELAY));
    srom_upload();
    spi_device_release_bus(s_sns);

    vTaskDelay(pdMS_TO_TICKS(10));
}

/* ── Lecture du mouvement ───────────────────────────────────────────────── */
static void motion_read(int16_t *dx, int16_t *dy, uint8_t *squal)
{
    reg_write(REG_Motion, 0x01);         /* fige les compteurs */
    (void)reg_read(REG_Motion);

    uint8_t xl = reg_read(REG_Delta_X_L), xh = reg_read(REG_Delta_X_H);
    uint8_t yl = reg_read(REG_Delta_Y_L), yh = reg_read(REG_Delta_Y_H);

    *dx = (int16_t)(((uint16_t)xh << 8) | xl);
    *dy = (int16_t)(((uint16_t)yh << 8) | yl);
    *squal = reg_read(REG_SQUAL);
}

/* ── Etablir la disposition du Motion_Burst, par la mesure ──────────────────
 *
 * Le burst (registre 0x50) rend plusieurs octets en UNE transaction : une seule
 * adresse, un seul tSRAD — et en mode burst il vaut 35 us au lieu de 160
 * (Table 5, p. 16). Un releve complet passe de ~1,9 ms a ~90 us.
 *
 * Probleme : NI la datasheet du 3389 (20 pages) NI celle du 3360 ne decrivent
 * la disposition des octets. Elle circule dans les implementations
 * communautaires, mais on ne la recopie pas sans preuve.
 *
 * Methode : afficher cote a cote les octets du burst et les memes grandeurs
 * lues registre par registre. Au repos, SQUAL et Shutter sont stables et
 * identifiables ; en bougeant la souris, les octets Delta se mettent a varier.
 * Deux captures suffisent a etablir la correspondance par observation.
 *
 * Procedure du burst :
 *   1. ecrire n'importe quoi dans Motion_Burst (0x50) pour l'armer
 *   2. NCS bas, envoyer 0x50 (adresse seule, pas de bit d'ecriture)
 *   3. attendre tSRAD_MOTBR = 35 us
 *   4. lire N octets d'affilee, sans relever NCS
 *   5. NCS haut, puis tBEXIT = 500 ns avant toute autre transaction SPI
 */
#define BURST_N 16

static void burst_read(uint8_t *out, size_t n)
{
    reg_write(REG_Motion_Burst, 0x00);      /* arme le mode burst */

    uint8_t addr = REG_Motion_Burst;        /* MSB a 0 : lecture */
    cs_low();
    spi_tx(&addr, NULL, 1);
    esp_rom_delay_us(35);                   /* tSRAD_MOTBR, Table 5 p. 16 */
    spi_tx(NULL, out, n);                   /* n octets d'affilee */
    cs_high();
    esp_rom_delay_us(5);                    /* tBEXIT = 500 ns, large */
}

static void burst_compare(void)
{
    uint8_t b[BURST_N];
    burst_read(b, BURST_N);

    /* Reference : les memes grandeurs, lues une par une juste apres. */
    uint8_t mot = reg_read(REG_Motion);
    uint8_t xl = reg_read(REG_Delta_X_L), xh = reg_read(REG_Delta_X_H);
    uint8_t yl = reg_read(REG_Delta_Y_L), yh = reg_read(REG_Delta_Y_H);
    uint8_t sq = reg_read(REG_SQUAL);
    uint8_t sl = reg_read(REG_Shutter_Lower), sh = reg_read(REG_Shutter_Upper);

    char l[BURST_N * 3 + 1]; int n = 0;
    for (unsigned i = 0; i < BURST_N; i++)
        n += snprintf(l + n, sizeof(l) - n, "%02X ", b[i]);

    ESP_LOGI(TAG, "burst[%2d] %s", BURST_N, l);
    ESP_LOGI(TAG, "   refs   Motion=%02X dXl=%02X dXh=%02X dYl=%02X dYh=%02X "
                  "SQUAL=%02X Shl=%02X Shh=%02X",
             mot, xl, xh, yl, yh, sq, sl, sh);
}

/* ── Diagnostic : SQUAL est-il vraiment bruite, ou est-ce ma lecture ? ──────
 *
 * Au banc du 2026-08-25, SQUAL alternait entre ~15 et ~80 d'un echantillon a
 * l'autre alors que Shutter restait stable a ~47. Un obturateur stable veut dire
 * un eclairement et une mise au point stables : le probleme n'est donc pas
 * optique, ou alors il faudrait qu'il le soit sans toucher a la quantite de
 * lumiere, ce qui n'a pas de sens.
 *
 * L'autre suspect est la boucle de lecture elle-meme, qui fige les compteurs par
 * reg_write(Motion, 0x01) avant de lire. Cette rafale lit SQUAL SEUL, sans
 * toucher a Motion, a 5 ms d'intervalle. Si la dispersion disparait, c'etait
 * bien la sequence de lecture ; si elle reste, c'est la surface ou l'optique. */
static void squal_probe(void)
{
    enum { N = 40 };
    uint8_t v[N];
    for (int i = 0; i < N; i++) { v[i] = reg_read(REG_SQUAL); vTaskDelay(pdMS_TO_TICKS(5)); }

    unsigned mn = 255, mx = 0, som = 0;
    char ligne[N * 4 + 1]; int n = 0;
    for (int i = 0; i < N; i++) {
        if (v[i] < mn) mn = v[i];
        if (v[i] > mx) mx = v[i];
        som += v[i];
        n += snprintf(ligne + n, sizeof(ligne) - n, "%u ", v[i]);
    }
    ESP_LOGI(TAG, "SQUAL x%d en rafale : %s", N, ligne);
    ESP_LOGI(TAG, "SQUAL min=%u max=%u moy=%u  (etendue %u)", mn, mx, som / N, mx - mn);
    ESP_LOGI(TAG, "  etendue faible => c'etait ma sequence de lecture.");
    ESP_LOGI(TAG, "  etendue large  => surface ou optique. Compare sur tapis vs bureau nu.");
}

/* ── Clics : anti-rebond par le contact NC, sans filtrage temporel ──────────
 *
 * Un SPDT ne rebondit pas "entre deux etats logiques" : pendant le rebond le
 * contact mobile n'est colle NI sur NO NI sur NC, donc les deux entrees sont
 * hautes (tirees par leurs 10 k). C'est un etat OBSERVABLE, et il suffit d'y
 * garder l'etat precedent pour supprimer le double-clic — aucun compteur, aucun
 * delai, aucune constante a regler.
 *
 *   repos    : NC ferme sur COM -> bas ; NO ouvert -> haut
 *   appuye   : NO ferme sur COM -> bas ; NC ouvert -> haut
 *   rebond   : les DEUX hauts               -> on ne conclut rien
 *   les deux bas : impossible physiquement  -> on ne conclut rien non plus
 */
typedef struct {
    gpio_num_t no, nc;
    bool       pressed;
    const char *nom;
    uint32_t   fronts;    /* transitions retenues */
    uint32_t   rebonds;   /* echantillons "les deux hauts" = rebond en cours */
    uint32_t   rebond_max;/* plus longue salve de rebond, en ms */
    uint32_t   rebond_cur;
} clic_t;

static clic_t s_clics[3] = {
    { PIN_SW_LEFT,  PIN_SW_LEFT_NC,  false, "G", 0, 0, 0, 0 },
    { PIN_SW_RIGHT, PIN_SW_RIGHT_NC, false, "D", 0, 0, 0, 0 },
    { PIN_SW_MID,   PIN_SW_MID_NC,   false, "M", 0, 0, 0, 0 },
};

/* Rend true si l'etat a change. Appelee a 1 kHz : sans ca la fenetre de rebond,
 * qui dure quelques millisecondes, passe entre deux echantillons et on ne peut
 * rien affirmer sur l'anti-rebond. */
static bool clic_update(clic_t *c)
{
    int no = gpio_get_level(c->no);
    int nc = gpio_get_level(c->nc);

    if (no == 1 && nc == 1) {          /* contact en l'air : rebond en cours */
        c->rebonds++;
        if (++c->rebond_cur > c->rebond_max) c->rebond_max = c->rebond_cur;
        return false;                  /* on garde l'etat precedent */
    }
    c->rebond_cur = 0;

    if (no == 0 && nc == 1) {          /* NO colle sur COM : appuye */
        bool change = !c->pressed;
        c->pressed = true;
        if (change) c->fronts++;
        return change;
    }
    if (no == 1 && nc == 0) {          /* NC colle sur COM : repos */
        bool change = c->pressed;
        c->pressed = false;
        if (change) c->fronts++;
        return change;
    }
    return false;                      /* les deux bas : impossible, on ignore */
}
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
void app_main(void)
{
    ESP_LOGI(TAG, "Conchodytes bring-up capteur — PMW3389");
    ESP_LOGI(TAG, "SCK=%d MISO=%d MOSI=%d NCS=%d MOTION=%d @ %d Hz mode 3",
             PIN_SCK, PIN_MISO, PIN_MOSI, PIN_SNS_NCS, PIN_SNS_MOTION, SNS_CLOCK_HZ);

    bus_init();
    vTaskDelay(pdMS_TO_TICKS(50));

    sensor_reset();

    /* L'identite APRES le reset mais AVANT le SROM : le reset garantit que le
     * port serie est aligne, et lire l'identite d'abord evite qu'un
     * televersement rate masque une puce qui ne repondait deja pas. */
    uint8_t id  = reg_read(REG_Product_ID);
    uint8_t inv = reg_read(REG_Inverse_Product_ID);
    uint8_t rev = reg_read(REG_Revision_ID);

    ESP_LOGI(TAG, "Product_ID = 0x%02X   (attendu 0x47, p. 20)", id);
    ESP_LOGI(TAG, "Inverse    = 0x%02X   (attendu 0xB8)", inv);
    ESP_LOGI(TAG, "Revision   = 0x%02X", rev);

    if (id == 0x00 && inv == 0x00) {
        ESP_LOGE(TAG, "tout a zero : MISO muet. Capteur non alimente, NCS mal");
        ESP_LOGE(TAG, "pilote, ou ligne coupee. U100 est-il depose et le rail");
        ESP_LOGE(TAG, "injecte a 1,9 V sur C100/C101/C103 ?");
    } else if (id == 0xFF && inv == 0xFF) {
        ESP_LOGE(TAG, "tout a un : MISO tire au haut, personne ne repond.");
    } else if ((id ^ inv) != 0xFF) {
        ESP_LOGE(TAG, "0x%02X ^ 0x%02X != 0xFF : le bus ment. Mode SPI, horloge,",
                 id, inv);
        ESP_LOGE(TAG, "ou le nRF24 qui repond a la place du capteur.");
    } else if (id != 0x47) {
        ESP_LOGW(TAG, "complement coherent mais 0x%02X n'est pas un PMW3389.", id);
    } else {
        ESP_LOGI(TAG, "=> PMW3389 confirme. Televersement du SROM.");
        sensor_load_srom();
    }

    /* Boucle de banc : mouvement, qualite d'image et obturateur. SQUAL compte
     * les points de contraste vus ; a zero avec un Shutter au plafond, le
     * capteur est aveugle — c'est la signature de D100 montee a l'envers, qui
     * empeche la LED interne de s'allumer (NOTES-V2.md point 6). */
    if (id == 0x47) squal_probe();

    nrf_probe();

    input_init();
    ESP_LOGI(TAG, "clics G=%d/%d D=%d/%d M=%d/%d (NO/NC), molette A=%d B=%d",
             PIN_SW_LEFT, PIN_SW_LEFT_NC, PIN_SW_RIGHT, PIN_SW_RIGHT_NC,
             PIN_SW_MID, PIN_SW_MID_NC, PIN_ENC_A, PIN_ENC_B);

    int32_t wheel_prev = 0;
    unsigned tour = 0;
    /* Le burst consomme les compteurs a chaque lecture : a 1 kHz chaque releve
     * ne vaut qu'une milliseconde de mouvement. On accumule avant d'afficher,
     * sinon un balayage franc se dissout en miettes indistinguables. */
    int32_t acc23 = 0, acc45 = 0; unsigned nacc = 0;

    /* Diagnostic molette : ENC_A/ENC_B restent a 00 meme avec un opaque entre
     * LD1 et LQ1, donc rien d'optique. Or on compte sur les 10 k EXTERNES
     * (R103/R104) et les tirages internes sont desactives. On les bascule
     * toutes les 5 s :
     *   passe a 11 avec tirage interne -> R103/R104 ne tirent pas (non montees,
     *     soudure froide, net coupe) ; le S3 peut prendre le relais.
     *   reste a 00 avec tirage interne -> quelque chose tire activement au bas,
     *     LQ1 en court ou pont de soudure. Le ~45 k interne est faible, mais il
     *     suffit a departager une ligne flottante d'une ligne tenue. */
    bool pu = false;
    while (1) {
        /* motion_read() est DESACTIVE pendant la campagne d'axes : il fige et
         * vide les compteurs de deplacement, donc il volait au burst le
         * mouvement qu'on cherche a mesurer. Les deux ne peuvent pas coexister
         * dans la meme boucle — c'est d'ailleurs l'argument pour ne garder que
         * le burst une fois sa disposition etablie. */
        int16_t dx = 0, dy = 0;
        uint8_t squal = reg_read(REG_SQUAL);

        uint8_t sl = reg_read(REG_Shutter_Lower);
        uint8_t sh = reg_read(REG_Shutter_Upper);

        int32_t w = s_wheel, dw = w - wheel_prev;
        wheel_prev = w;

        /* Niveaux bruts NO/NC en plus de l'etat decode : si un clic n'apparait
         * pas dans G/D/M alors que ses deux broches bougent, c'est la logique
         * qui est fausse et pas le cablage — et reciproquement. Au repos on
         * attend NO=1 NC=0 sur les trois. */
        ESP_LOGI(TAG, "dx=%6d dy=%6d SQ=%3u Sh=%4u MOT=%d | G%d D%d M%d | "
                      "brut G%d%d D%d%d M%d%d | AB=%d%d molette %+4ld (tot %6ld, rat %lu)",
                 dx, dy, squal, ((unsigned)sh << 8) | sl,
                 gpio_get_level(PIN_SNS_MOTION),
                 s_clics[0].pressed, s_clics[1].pressed, s_clics[2].pressed,
                 gpio_get_level(PIN_SW_LEFT),  gpio_get_level(PIN_SW_LEFT_NC),
                 gpio_get_level(PIN_SW_RIGHT), gpio_get_level(PIN_SW_RIGHT_NC),
                 gpio_get_level(PIN_SW_MID),   gpio_get_level(PIN_SW_MID_NC),
                 gpio_get_level(PIN_ENC_A),    gpio_get_level(PIN_ENC_B),
                 (long)dw, (long)w, (unsigned long)s_wheel_err);

        /* Octets 2-5 du burst, decodes sous les deux hypotheses. Bouger sur un
         * seul axe a la fois departage : si l'axe immobile reste a 0,
         * l'hypothese correspondante est la bonne. */
        if (id == 0x47) {
            uint8_t bb[12];
            burst_read(bb, 12);
            acc23 += (int16_t)(((uint16_t)bb[3] << 8) | bb[2]);
            acc45 += (int16_t)(((uint16_t)bb[5] << 8) | bb[4]);
            if (++nacc >= 1) {            /* la boucle fait deja 200 ms */
                if (acc23 || acc45)
                    ESP_LOGW(TAG, "sur 200 ms : paire(2,3)=%+7ld   paire(4,5)=%+7ld",
                             (long)acc23, (long)acc45);
                acc23 = acc45 = 0; nacc = 0;
            }
        }

        if (tour % 25 == 0) {
            pu = !pu;
            gpio_set_pull_mode(PIN_ENC_A, pu ? GPIO_PULLUP_ONLY : GPIO_FLOATING);
            gpio_set_pull_mode(PIN_ENC_B, pu ? GPIO_PULLUP_ONLY : GPIO_FLOATING);
            vTaskDelay(pdMS_TO_TICKS(5));
            ESP_LOGW(TAG, "molette : tirage interne %s -> AB=%d%d",
                     pu ? "ACTIF " : "coupe ",
                     gpio_get_level(PIN_ENC_A), gpio_get_level(PIN_ENC_B));
        }

        if (++tour % 25 == 0)
            ESP_LOGW(TAG, "rebond : G %lu fronts/%lu ms (max %lu) | D %lu/%lu (max %lu)"
                          " | M %lu/%lu (max %lu)",
                (unsigned long)s_clics[0].fronts, (unsigned long)s_clics[0].rebonds,
                (unsigned long)s_clics[0].rebond_max,
                (unsigned long)s_clics[1].fronts, (unsigned long)s_clics[1].rebonds,
                (unsigned long)s_clics[1].rebond_max,
                (unsigned long)s_clics[2].fronts, (unsigned long)s_clics[2].rebonds,
                (unsigned long)s_clics[2].rebond_max);

        vTaskDelay(pdMS_TO_TICKS(200));
    }
}

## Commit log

2026-08-07 Conchodytes : projet initial — souris sleeper pour coque Logitech M100
    Une souris sans fil qui garde l'apparence d'une M100 de bureau : capteur PMW3360,
    liaison nRF24 vers le dongle KaSe, le même récepteur que le clavier Niphargus.
    Repris du fork RandomDelta6/USB-Mouse (design USB filaire qui fonctionne) :
    - le contour du PCB, 39 x 78 mm, 27 éléments Edge.Cuts ;
    - les 6 empreintes que la coque impose et que Mae avait verrouillées —
    SW1/SW2/SW3 (clics), LD1/LQ1 (encodeur optique de molette), U2 (PMW3360) ;
    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
    [conchodytes.kicad_pcb, conchodytes.kicad_sch, mcu.kicad_sch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]
2026-08-07 fix : le décalage de références corrompait la feuille usbc
    Mon script de copie décalait toute chaîne de la forme lettre+chiffre, pas
    seulement les références. Sur usbc (offset +40), il a donc transformé :
    (paper "A4") -> "A44" -> KiCad : « Page type non valide, ligne 6 »
    les noms de pins de l'USB-C : A1->A41, CC1->CC41, SBU1->SBU41, VDD33->VDD73
    D'où la feuille qui s'ouvrait vide et l'échec de chargement des feuilles
    hiérarchiques.
    Le décalage ne s'applique plus qu'aux vraies références, et seulement là où
    elles sont déclarées : (property "Reference" "U13") et (reference "U13") dans
    les blocs d'instances. Copie refaite : paper A4 rétabli, noms de pins intacts,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
    [usbc.kicad_sch]
2026-08-07 fix : nom de projet dans les blocs d'instances
    Les feuilles copiées déclaraient (project "Mouse") — le nom que j'avais passé au
    script de copie — alors que le projet s'appelle conchodytes.kicad_pro. KiCad
    réparait donc la hiérarchie à chaque ouverture, d'où le message « Une erreur a
    été rencontrée lors du chargement du schéma et a été corrigée automatiquement ».
    223 occurrences corrigées. Les quatre feuilles se rechargent maintenant sans
    aucune réparation. ERC : 0 erreur, 96 warnings de bibliothèque.
    Claude-Session: https://claude.ai/code/session_01GfX5RmekmQi78Dm37qsT4Z
    [conchodytes.kicad_sch, mcu.kicad_sch, power.kicad_sch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]
2026-08-07 élagage des feuilles + réparation des tables de bibliothèques
    Mae a élagué dans l'éditeur :
    - mcu : 108 -> 16 composants. Restent le S3, le nRF24, leurs découplages, le
    connecteur de prog et les 100 ohms. Partis : la matrice 26 switchs / 24
    diodes, les 11 TVS, le TRRS, l'écran, le trackpad.
    - usbc : 6 -> 4 composants. Le hub CH334R (U53) est parti, il venait du coffre
    P4 et n'avait rien à faire dans une souris. Restent J48, U54 (USBLC6) et les
    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
    [conchodytes.kicad_sch, mcu.kicad_sch, power.kicad_sch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]
2026-08-07 feuille sensor + correction de mon analyse de la radio
    La liaison S3 <-> nRF24 est intacte : je l'avais lue comme cassée alors que
    chaque ligne passe par sa résistance série de 100 ohms, nommée localement d'un
    côté (SCK_L / MOSI_L / MISO_L) et anonyme de l'autre. Rien à réparer :
    U8.5 SCK -R30- U6.31 (GPIO38) U8.4 CSN -R36- U6.9 (GPIO16)
    U8.6 MOSI -R18- U6.33 (GPIO40) U8.3 CE -R39- U6.8 (GPIO15)
    U8.7 MISO -R16- U6.32 (GPIO39) U8.8 IRQ -R41- U6.34 (GPIO41)
    Ajout de sensor.kicad_sch, cinquième feuille de la hiérarchie, avec la liste de
    ce qui doit y être posé et les références exactes à respecter — SW1/SW2/SW3,
    LD1/LQ1, U2 — pour que le F8 retrouve les empre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
    [conchodytes.kicad_sch, mcu.kicad_sch, sensor.kicad_sch]
2026-08-07 schéma du capteur, de l'encodeur et des clics
    sensor.kicad_sch, généré et vérifié par netlist :
    - U2 PMW3360 — SPI partagé avec le nRF24 (SCK_L/MOSI_L/MISO_L, déjà routés vers
    le S3 par leurs 100 ohms), plus SNS_NCS et SNS_MOTION en propre. NRESET tiré
    au 3,3 V, LED_P pilote D100 via R101.
    - U100 LDO 1,8 V dédié : VDD et VDDPIX du capteur ne sont PAS en 3,3 V (plage
    usuelle 1,8-2,1 V, à confirmer datasheet). VDDIO reste en 3,3 V.
    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
    [mcu.kicad_sch, sensor.kicad_sch]
2026-08-07 tout sur la grille de 1,27 + correction du brochage du LDO
    Mes origines de placement (100, 60...) n'étaient pas des multiples de 1,27, donc
    rien de ce qui en dérivait ne tombait sur la grille : 89 endpoint_off_grid, et
    Mae aurait dû tout redéplacer à la main. Les coordonnées sont maintenant snappées
    à la source, dans les primitives de placement, de fil et de label. Vérifié :
    zéro coordonnée hors grille hors lib_symbols, et les 7 liaisons capteur <-> S3
    ont survécu au snap.
    Correction électrique : j'avais câblé le LDO du capteur à l'envers — 3,3 V sur
    la pin de masse. Le symbole porte encore le lib_id MCP1700 mais son brochage a
    été corrigé pour le HT7833 SOT-89 pendant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
    [conchodytes.kicad_sch, mcu.kicad_sch, sensor.kicad_sch]
2026-08-07 lien schéma <-> PCB : les 6 empreintes de la coque sont remariées
    Les empreintes verrouillées portaient encore les path UUID du fork
    (/00000000-...-62f7695e), donc aucune n'était liée aux symboles du schéma : un
    F8 les aurait dissociées ou dupliquées, et les positions imposées par la coque
    étaient perdues.
    Chaque path pointe maintenant sur l'uuid du symbole correspondant dans
    sensor.kicad_sch — SW1/SW2/SW3, LD1, LQ1, U2. Même technique que la
    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
    [conchodytes.kicad_pcb, sensor.kicad_sch]
2026-08-07 empreinte du nRF24 rapatriée
    MaeLid.pretty avait été copié depuis le fork Mouse, où il ne contient que
    D_SOD-123 et LOGO : NRF24L01.kicad_mod vit dans le MaeLid du Niphargus. Le F8
    de Mae a donc importé 60 composants sur 61 et laissé U8 de côté.
    Vérifié dans la foulée : les 24 empreintes distinctes référencées par le schéma
    sont toutes résolues dans les bibliothèques du projet.
    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
    [conchodytes.kicad_pcb]
2026-08-07 contour : renflement pour le connecteur USB-C
    Le J48 dépassait de 5,76 mm au-dessus du bord haut : le connecteur n'avait pas
    de matière sous lui, donc pas d'USB possible. Plutôt que de le reculer — il doit
    rester à l'avant, là où sortait le câble de la M100 — le contour reçoit un
    renflement local : x 90,0 à 102,5, remontant de y=74,85 à y=68,5.
    Le connecteur occupe x 90,98..101,62 et remonte à 69,09 : il a 0,9 mm de marge
    tout autour et repose entièrement sur la carte.
    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
    [conchodytes.kicad_pcb, mcu.kicad_sch, sensor.kicad_sch]
2026-08-07 logos Niphargus importés dans la bibliothèque
    Les 5 empreintes de logo vivaient seulement dans le MaeLid du clavier — le
    MaeLid de Conchodytes venait du fork Mouse, qui ne contient que D_SOD-123 et
    LOGO. Même cause que le nRF24 manquant au premier F8.
    Copiées : Niphargus_10mm_Cu et _silk (8,8 x 9,0 mm — la crevette),
    niphargus_19mm_silk (17,7 x 18,1), Niphargus_text_3mm_Cu et _silk
    (15,6 x 3,9 — le mot). Sur le clavier, HS1/HS2 utilisent la version cuivre au
    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
    [conchodytes.kicad_pcb, power.kicad_sch]
2026-08-07 baseline re-référencée sur le projet complet
    L'ancienne baseline (ERC 1/93, DRC 4/11) datait du jour où le dépôt ne contenait
    que le contour et les 6 empreintes de la coque : elle comparait à un état qui
    n'avait plus de sens et gardait le check au rouge en permanence, donc sans
    valeur d'alerte.
    Nouvelle référence sur le projet schématisé, importé et routé :
    ERC 14 erreurs / 14 warnings DRC 26 erreurs / 19 warnings
    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
    [conchodytes.kicad_pcb]
2026-08-07 readme : état réel du projet et contraintes du bloc capteur
    Le README décrivait encore un projet à peine créé. Il porte maintenant l'état
    (schéma vérifié, board routé, 0 pad non connecté), le brochage du capteur et les
    trois contraintes qui coûteraient cher à découvrir plus tard : le rail 1,8 V de
    VDD/VDDPIX, la lentille LM19-LSI incompatible avec l'optique d'origine, et les
    six références verrouillées à ne pas renommer.
    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
2026-08-08 sérigraphie, logos annotés, prêt pour la pré-release
    Mae a posé « Conchodytes » et « V1.0.0 08/2026 By mornepousse » au dos, plus le
    logo Niphargus en cuivre et le symbole Open Source Hardware.
    Les deux logos portaient la référence REF** : annotés HS1 et HS2, sinon le
    prochain F8 les traiterait comme des composants fantômes.
    Baseline re-référencée sur cet état (DRC 26/20, ERC 14/14) : la sérigraphie
    ajoute 1 warning text_thickness, assumé.
    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
    [conchodytes.kicad_pcb]
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2026-08-25 mesure batterie : quitter ADC2 pour ADC1 en v2
    Le pont 1M/1M ne bouge pas : le rapport est bon, les 2,1 uA de fuite sont
    le bon arbitrage pour un objet endormi, et C21 rend le pont haute impedance
    utilisable. L'erreur de fuite ADC se rattrape par calibration firmware.
    C'est la broche qui pose probleme. VBAT_SENSE arrive sur la broche 21 du
    module, soit GPIO13 / ADC2_CH2 (datasheet ESP32-S3-WROOM-1/1U, table 3-1,
    p. 11). L'ADC2 du S3 est partage avec le driver Wi-Fi : la mesure batterie
    interdit donc le Wi-Fi sur la carte. Ca marche aujourd'hui puisque la radio
    est un nRF24, mais autant lever l'hypotheque plutot que la documenter.
    Cible : broche 12 = GPIO8 = ADC1_CH7, libre et hors strappin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
2026-08-26 schema REV2 : LQ1 recable, D100 supprimee, VBAT_SENSE sur ADC1, U100 corrige
    LQ1 etait cable a l'envers depuis le portage du fork USB-Mouse. Le symbole
    Optical_Mouse:LQ ne nommait ses broches que "1, 2, 3", sans fonction, et le
    portage a suppose un double phototransistor A/COM/B. Le schema d'origine de la
    M100 dit autre chose : broche 1 = DATA, 2 = VCC, 3 = GND.
    La carte alimentait donc le capteur a l'envers — son VCC a la masse, sa masse
    tiree au 3,3 V par R104. Le courant passait par la diode de substrat interne et
    clampait les deux nets a 0,65 V, insensible a la lumiere comme au pilotage.
    Deux LQ1 ont ete dessoudes avant que la confrontation au schema source ne donne
    la reponse.
    - L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
    [conchodytes.kicad_pcb, mcu.kicad_sch, sensor.kicad_sch]
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2026-08-26 fabrication REV2 : gerbers, BOM et CPL envoyes chez JLCPCB
    Generes le 2026-08-26 a 13h35, depuis conchodytes.kicad_pcb sauvegarde a la
    meme minute — les fichiers correspondent bien a la carte corrigee.
    Le repertoire gerber/ reste ignore par .gitignore ; l'archive
    GERBER-conchodytes.zip est ce qui est parti chez le fabricant et suffit a
    reconstituer l'envoi.
    .gitignore : ignore le build ESP-IDF de bringup/ (138 Mo regenerables) et son
    sdkconfig genere.
    Claude-Session: https://claude.ai/code/session_01VhxWZJVUd4SHAcp3eUFVJV
    [BOM-conchodytes.csv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]
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2026-09-21 firmware lives in Conchodytes-firmware (board, pinout contract, releases) — this repository stays the hardware; the board moved here on 2026-09-21 is reverted
    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
